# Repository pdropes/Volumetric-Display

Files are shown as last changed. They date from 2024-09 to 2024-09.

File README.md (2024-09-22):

# Volumetric-Display, with ESP32 and LED matrix

VOXEL by #dropes

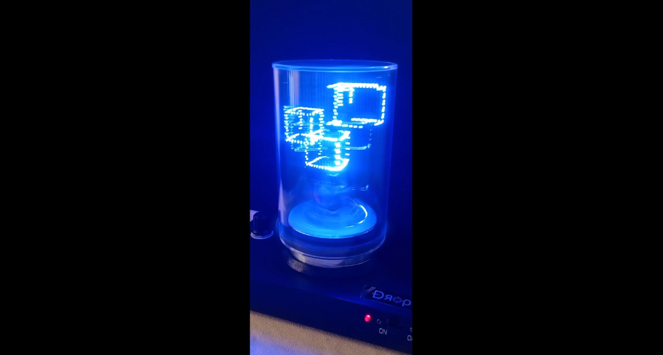
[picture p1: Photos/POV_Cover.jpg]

Video: https://youtu.be/vmjfssugH9E

## VOXEL - HARDWARE

- The motor I used the head of a VCR, after opening it, I placed the power transmitter coils inside, the ferrites had to be filed (very carefully) to fit well and then glued them.
- The distance between the coils is very important and must be calibrated in advance, with the help of a power supply with adjustable maximum current. In the receiver, you must connect a low value resistance 2ohms, or a 20W 12V lamp, with a multimeter to monitor the current passing through it.
- Then the emitter must be supplied with 12V, without progressive increases, the supply must be immediate or it will burn out, maximum current of 2A to start.
- The objective is to have the maximum current measured in the receiver, but without saturating the coils, to do this the distance between the coils is slowly reduced, the current rises to a point, then starts to fall, the distance from the coil must be recorded highest measured current.
- It is likely that the source used in these tests will present a current peak when calibrating the distances. You must be very careful not to overheat both the transmitter and the receiver, and you must immediately move the coils away.
- Both must have a heat sink, both on the two boards and on the emitter power transistors.
- The power supply must be at least 50W, with a voltage of 18V to 24V, with a lower voltage the wireless power transmitter will overheat, requiring more current to compensate.
- The IR transmitter and receiver are inside the head through two holes, this head must rotate without touching anything.
- Assembling all the components requires some skills, if you are not able to solder with an oven or heating plate and hot air station, I recommend ordering the PCBs with the components already soldered, joining the two plates will have to be done later.
- The most difficult are the 1024 “0603 LEDs” and the 64 “controller ICs”.
- The PCBs must have the minimum thickness possible, with 0.6mm being a good value, with the LED controller ICs touching them. Their color doesn't matter much, in rotation it becomes unnoticeable.

More calibrations:
- The 1st balance is static, with the boards horizontal and without the tube, weights must be placed, so that no differences are noticed when rotating manually, always horizontally.
- The dynamic balance was achieved by placing a piezo on one of the legs of the box, visualizing the signal amplitude on the oscilloscope, then placing washers at certain points, where the displayed amplitude reduces.
- The tube alignment must also be done, looking for eccentricity and having as little oscillation as possible.
  
These processes can be tedious and time-consuming, be patient.

## VOXEL - SOFTWARE

Project carried out in Arduino IDE v2.2.1
The 1st programming must be via USB, the rest can be via Wi-Fi for the convenience of keeping the tube, this is the best option, the Arduino-ota routine must be configured in advance, with the name and password of the network to be connected, this part must always remain in the code.
Although you chose the ESP32S2, another type of ESP32 should work, it uses the internal RAM for animations, and the optional PSRAM, for pre-calculation of heavier animations.
The USB connection is direct, without the need for a separate IC for this.
Programming the ESP32 must be done with the engine stopped, in all cases.

Programming steps:
- Connect the VOXEL board directly via USB to the PC.
- Open Arduino, in BOARDS MANAGER, find and install “esp32 by Espressif”
- In LIBRARIES MANAGER, find and install “Arduino_ESP32_OTA by Arduino”
- In TOOLS-BOARDS-ESP32-ESP32S2 Dev Module, choose the COM where the VOXEL is connected
- Check the board settings with the attached file “Arduino V2.2.1 config.png”.
- In VOXEL.INO change the name and password of the local network 
- Compile and upload to ESP32.
- After that, all programming does not require a USB connection, on the Arduino IDE, the Wi-Fi port must be visible.
- If you always intend to program via Wi-Fi, the Arduino-ota settings in VOXEL.ino must remain.

New Animation:
- When programming more effects, you must create a blank file in the same folder, extension .h
- Open VOXEL.ino
- Include the new file name in “FX”
- Next, the “FXlast” declaration, must be changed to the last effect number.
- void ISR_IR, which is the int. that detects the complete turn via IR, the procedure to be carried out in this new effect must be included (check the examples already written).
- void ARDUINO_ISR_ATTR, this is a timer that is run 100 times per turn, the reference of the new effect must also be included, or copy 3 lines from another, so that it can be clearly displayed.
- Shared.h file shares variables between VOXEL.ino and effect.h, or use static variables to avoid conflicts.

## WARNING !
The use of acrylic tube is NECESSARY in this assembly!
It keeps the boards in place at the top, prevents air friction, and ensures GREATER SAFETY to the touch.
Its absence can cause PHYSICAL OR VISION DAMAGE, the rotation speed corresponds to between 25 and 42 km/h!

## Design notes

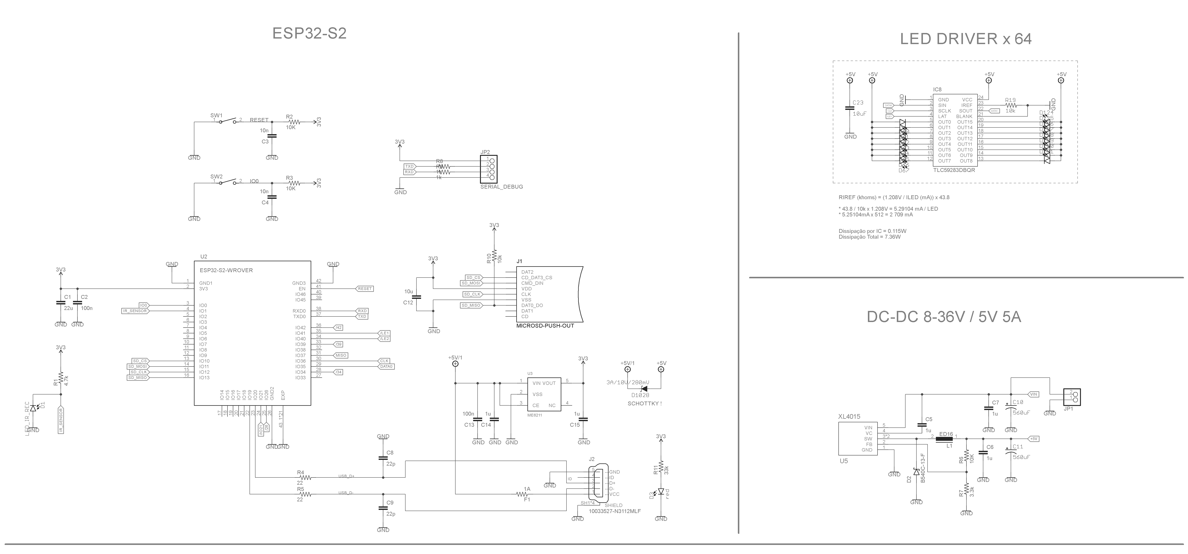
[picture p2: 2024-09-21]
Hardware/Schematic_resume.png

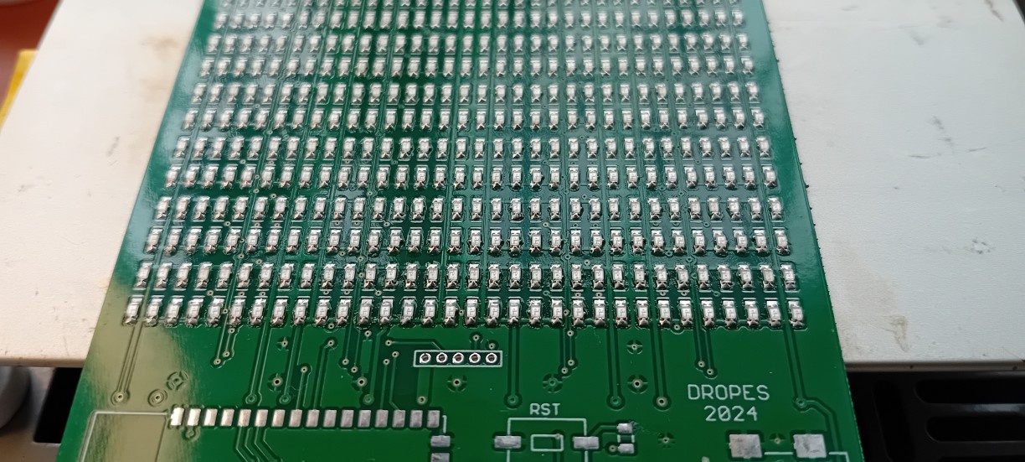
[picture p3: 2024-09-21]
Photos/POV_07.jpg

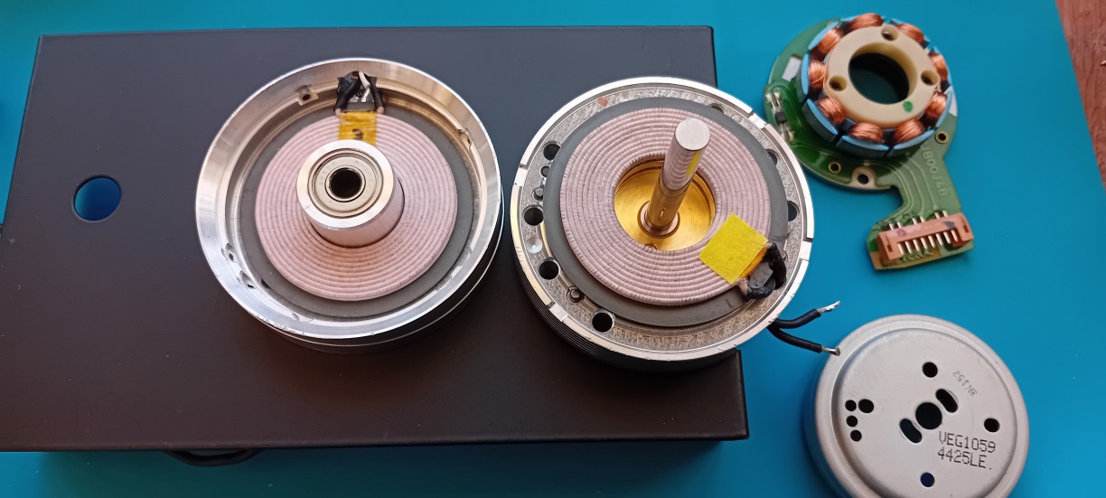
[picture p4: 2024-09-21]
Photos/POV_12.jpg

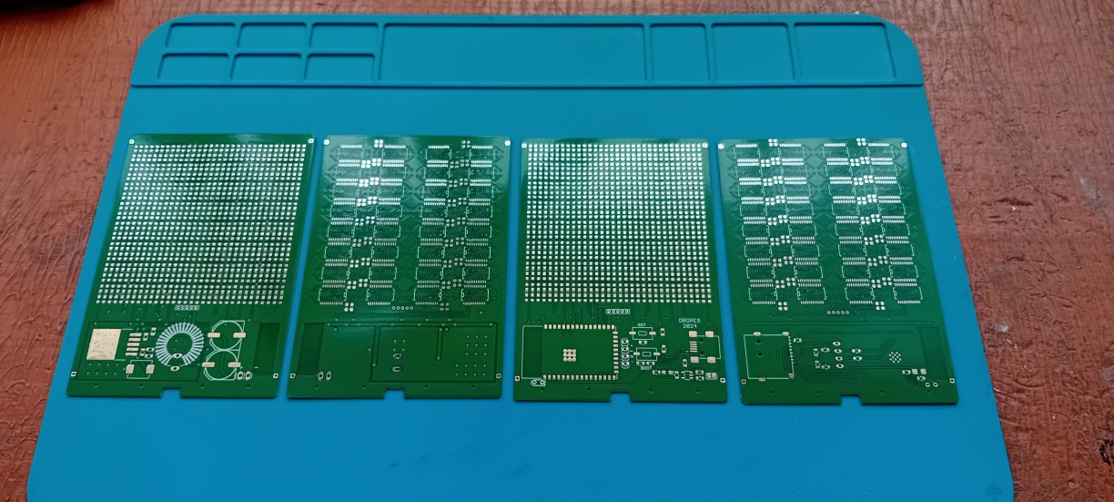
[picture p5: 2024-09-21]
Photos/POV_06.jpg

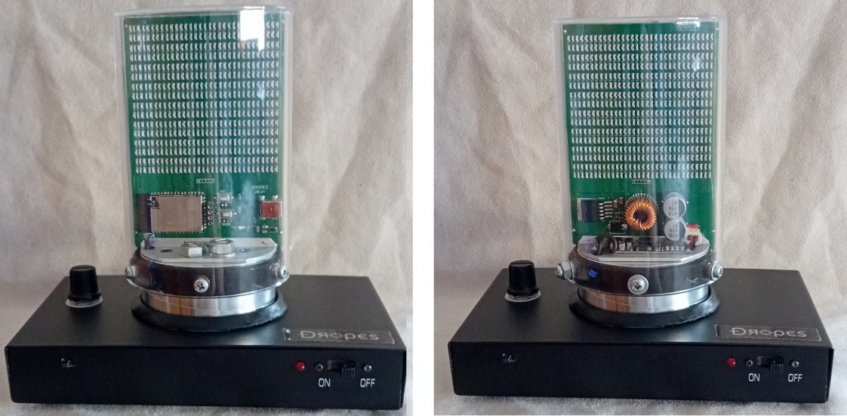
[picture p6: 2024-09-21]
Photos/POV_17.jpg

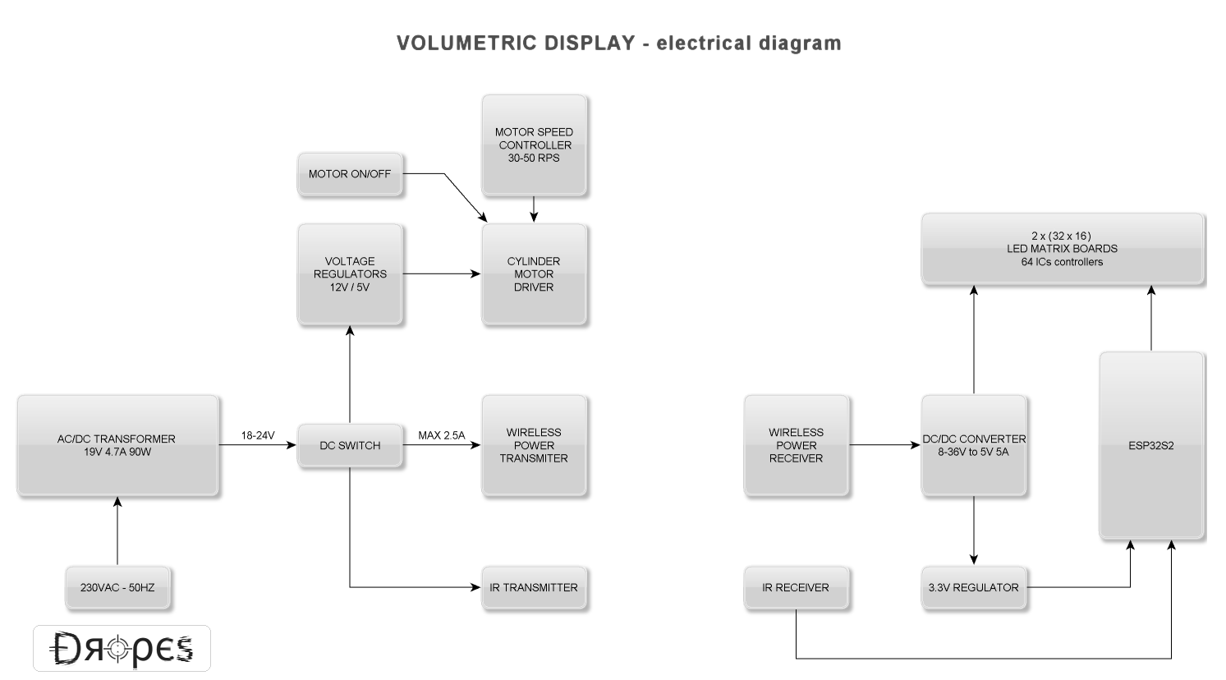
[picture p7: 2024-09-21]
Electrical Diagram.png

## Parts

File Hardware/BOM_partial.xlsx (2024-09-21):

MOUSER | Quantity | Description | Link
TLC59283DBQR | 64 | Drive 16 LEDs | https://pt.mouser.com/ProductDetail/595-TLC59283DBQR
GRM188R60J106KE47J | 64 | 0603 10u 6.3V | https://pt.mouser.com/ProductDetail/81-GRM188R60J106KE7J
CRGH0603J10K | 64 | 0603 10k 0,2W | https://pt.mouser.com/ProductDetail/279-CRGH0603J10K
10033527-N3112MLF | 1 | Mini-USB connector | https://pt.mouser.com/ProductDetail/649-10033527N3112MLF
PTS636 SM25F SMTR LFS | 2 | Micro-switch | https://pt.mouser.com/ProductDetail/611-PTS636SM25FSMTRL
Various passive components |  | Check schematic
ALIEXPRESS | Quantity | Description
Charging board | 2 | xl4015 5A | https://pt.aliexpress.com/item/32711173698.html
LEDs | 2 | 0603 1000 blue LEDs | https://pt.aliexpress.com/item/1005005469107318.html
ME6211 | 1 | LDO 3,3V | https://pt.aliexpress.com/item/1005006036398325.html
Transparent acrylic tube | 1 | Diameter: 75mm / Lenght: 50cm | https://pt.aliexpress.com/item/1005003660995564.html
Wireless power transmitter | 1 | 50W 12-24V 2,5A | https://pt.aliexpress.com/item/1005005666251775.html
DIVERSOS | Quantity | Description
ESP32S2 WROVER | 1 | Flash: 4MB, PSRAM: 2MB | https://mauser.pt/catalog/product_info.php?products_id=096-8584
PCBWAY | 1 | 2 different PCBs per assembly | https://www.pcbway.com/orderonline.aspx
PSRAM is used for some more complex animations, where this is handled in advance at startup
ESP32 with PSRAM, and SD support its optional
Check ESP32 compatibilities when choosing another different module

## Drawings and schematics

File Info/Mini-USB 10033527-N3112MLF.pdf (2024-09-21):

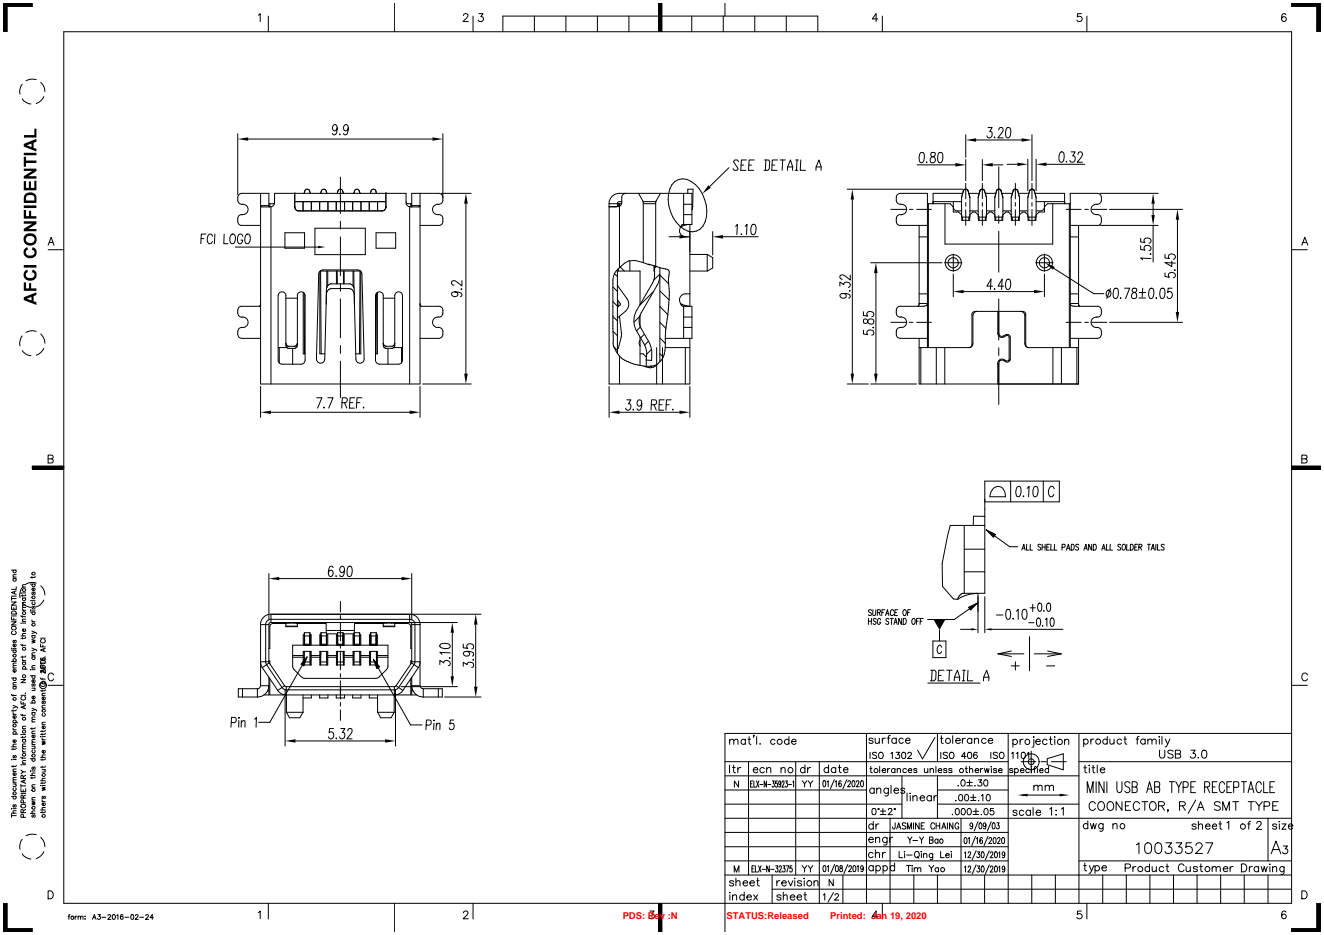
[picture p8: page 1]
PDS: Rev :N; STATUS:Released; Printed: Jan 19, 2020

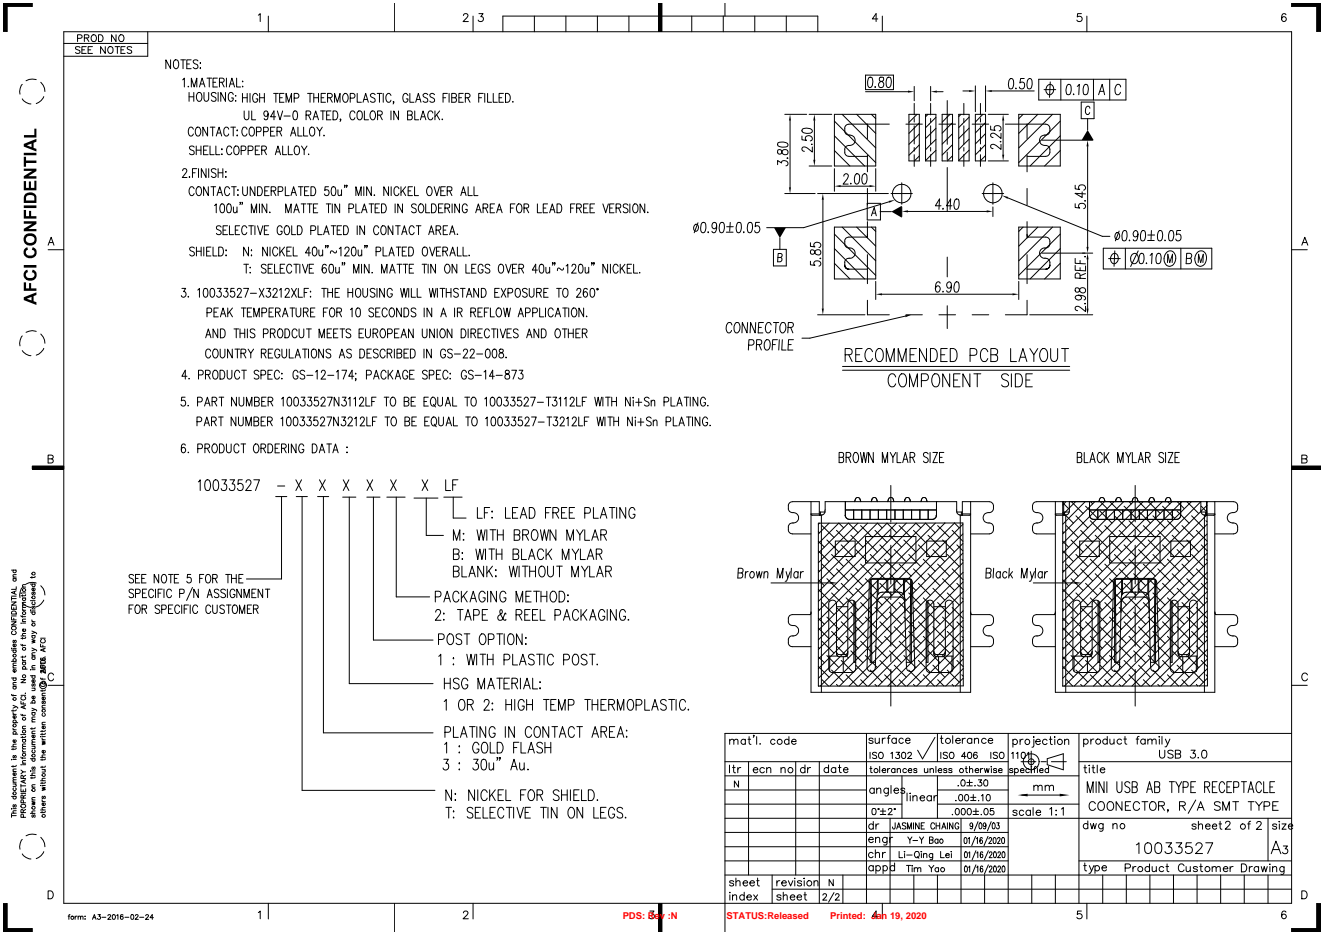
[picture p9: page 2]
PDS: Rev :N; STATUS:Released; Printed: Jan 19, 2020

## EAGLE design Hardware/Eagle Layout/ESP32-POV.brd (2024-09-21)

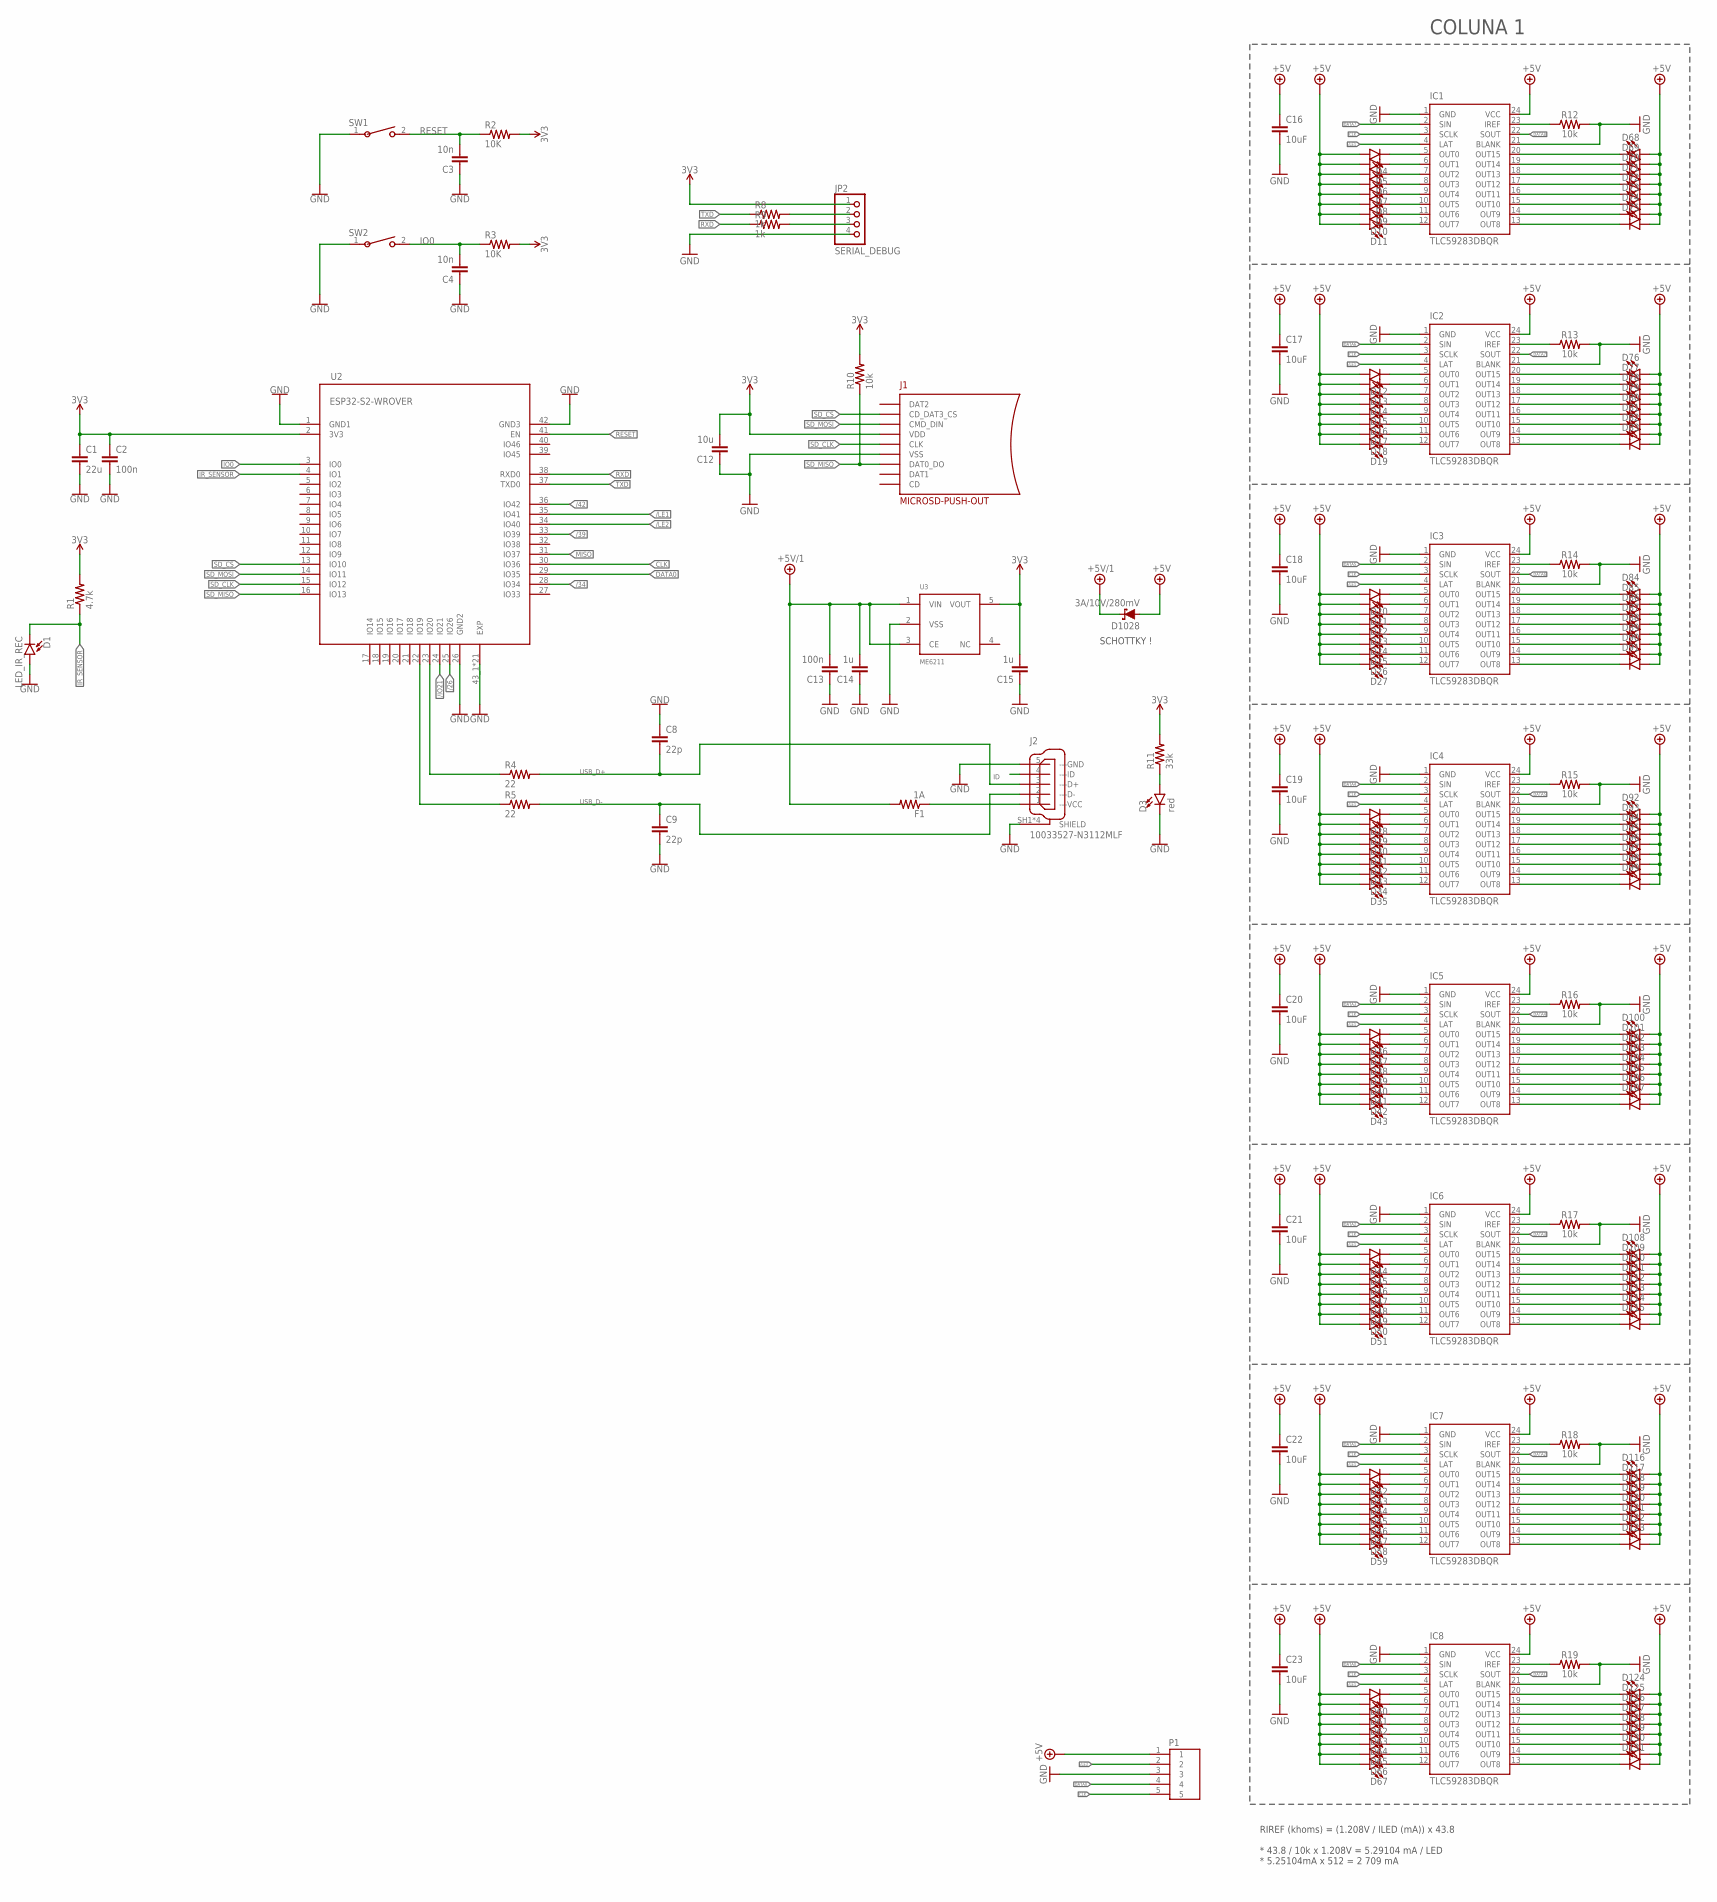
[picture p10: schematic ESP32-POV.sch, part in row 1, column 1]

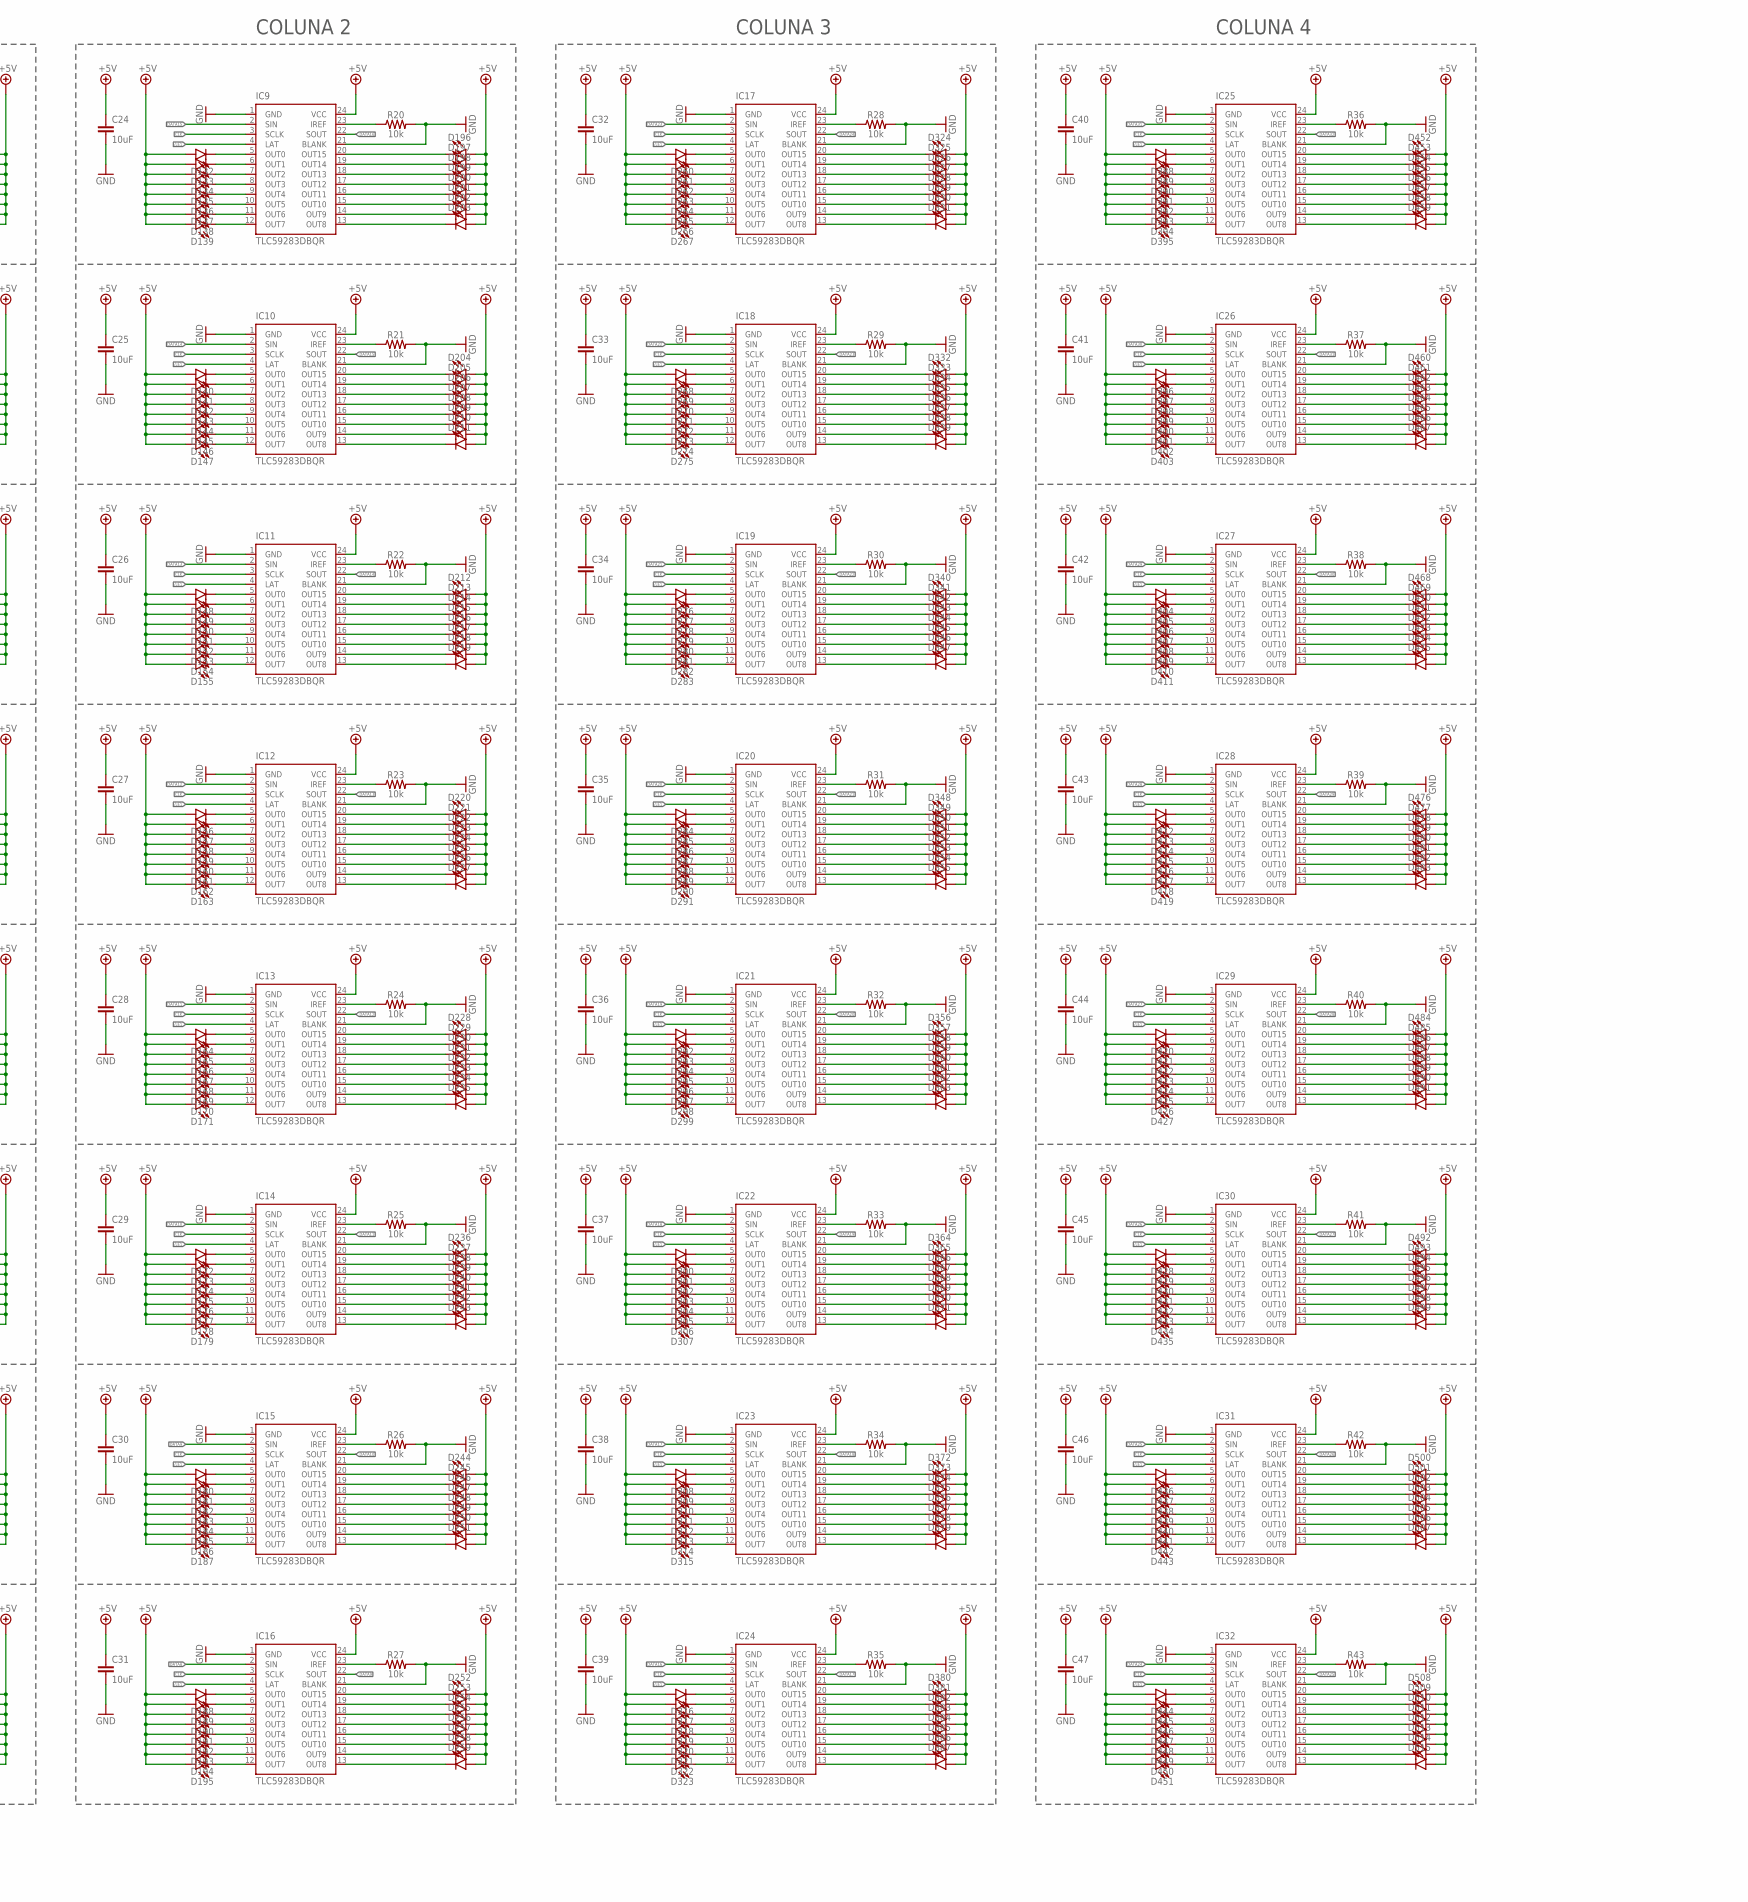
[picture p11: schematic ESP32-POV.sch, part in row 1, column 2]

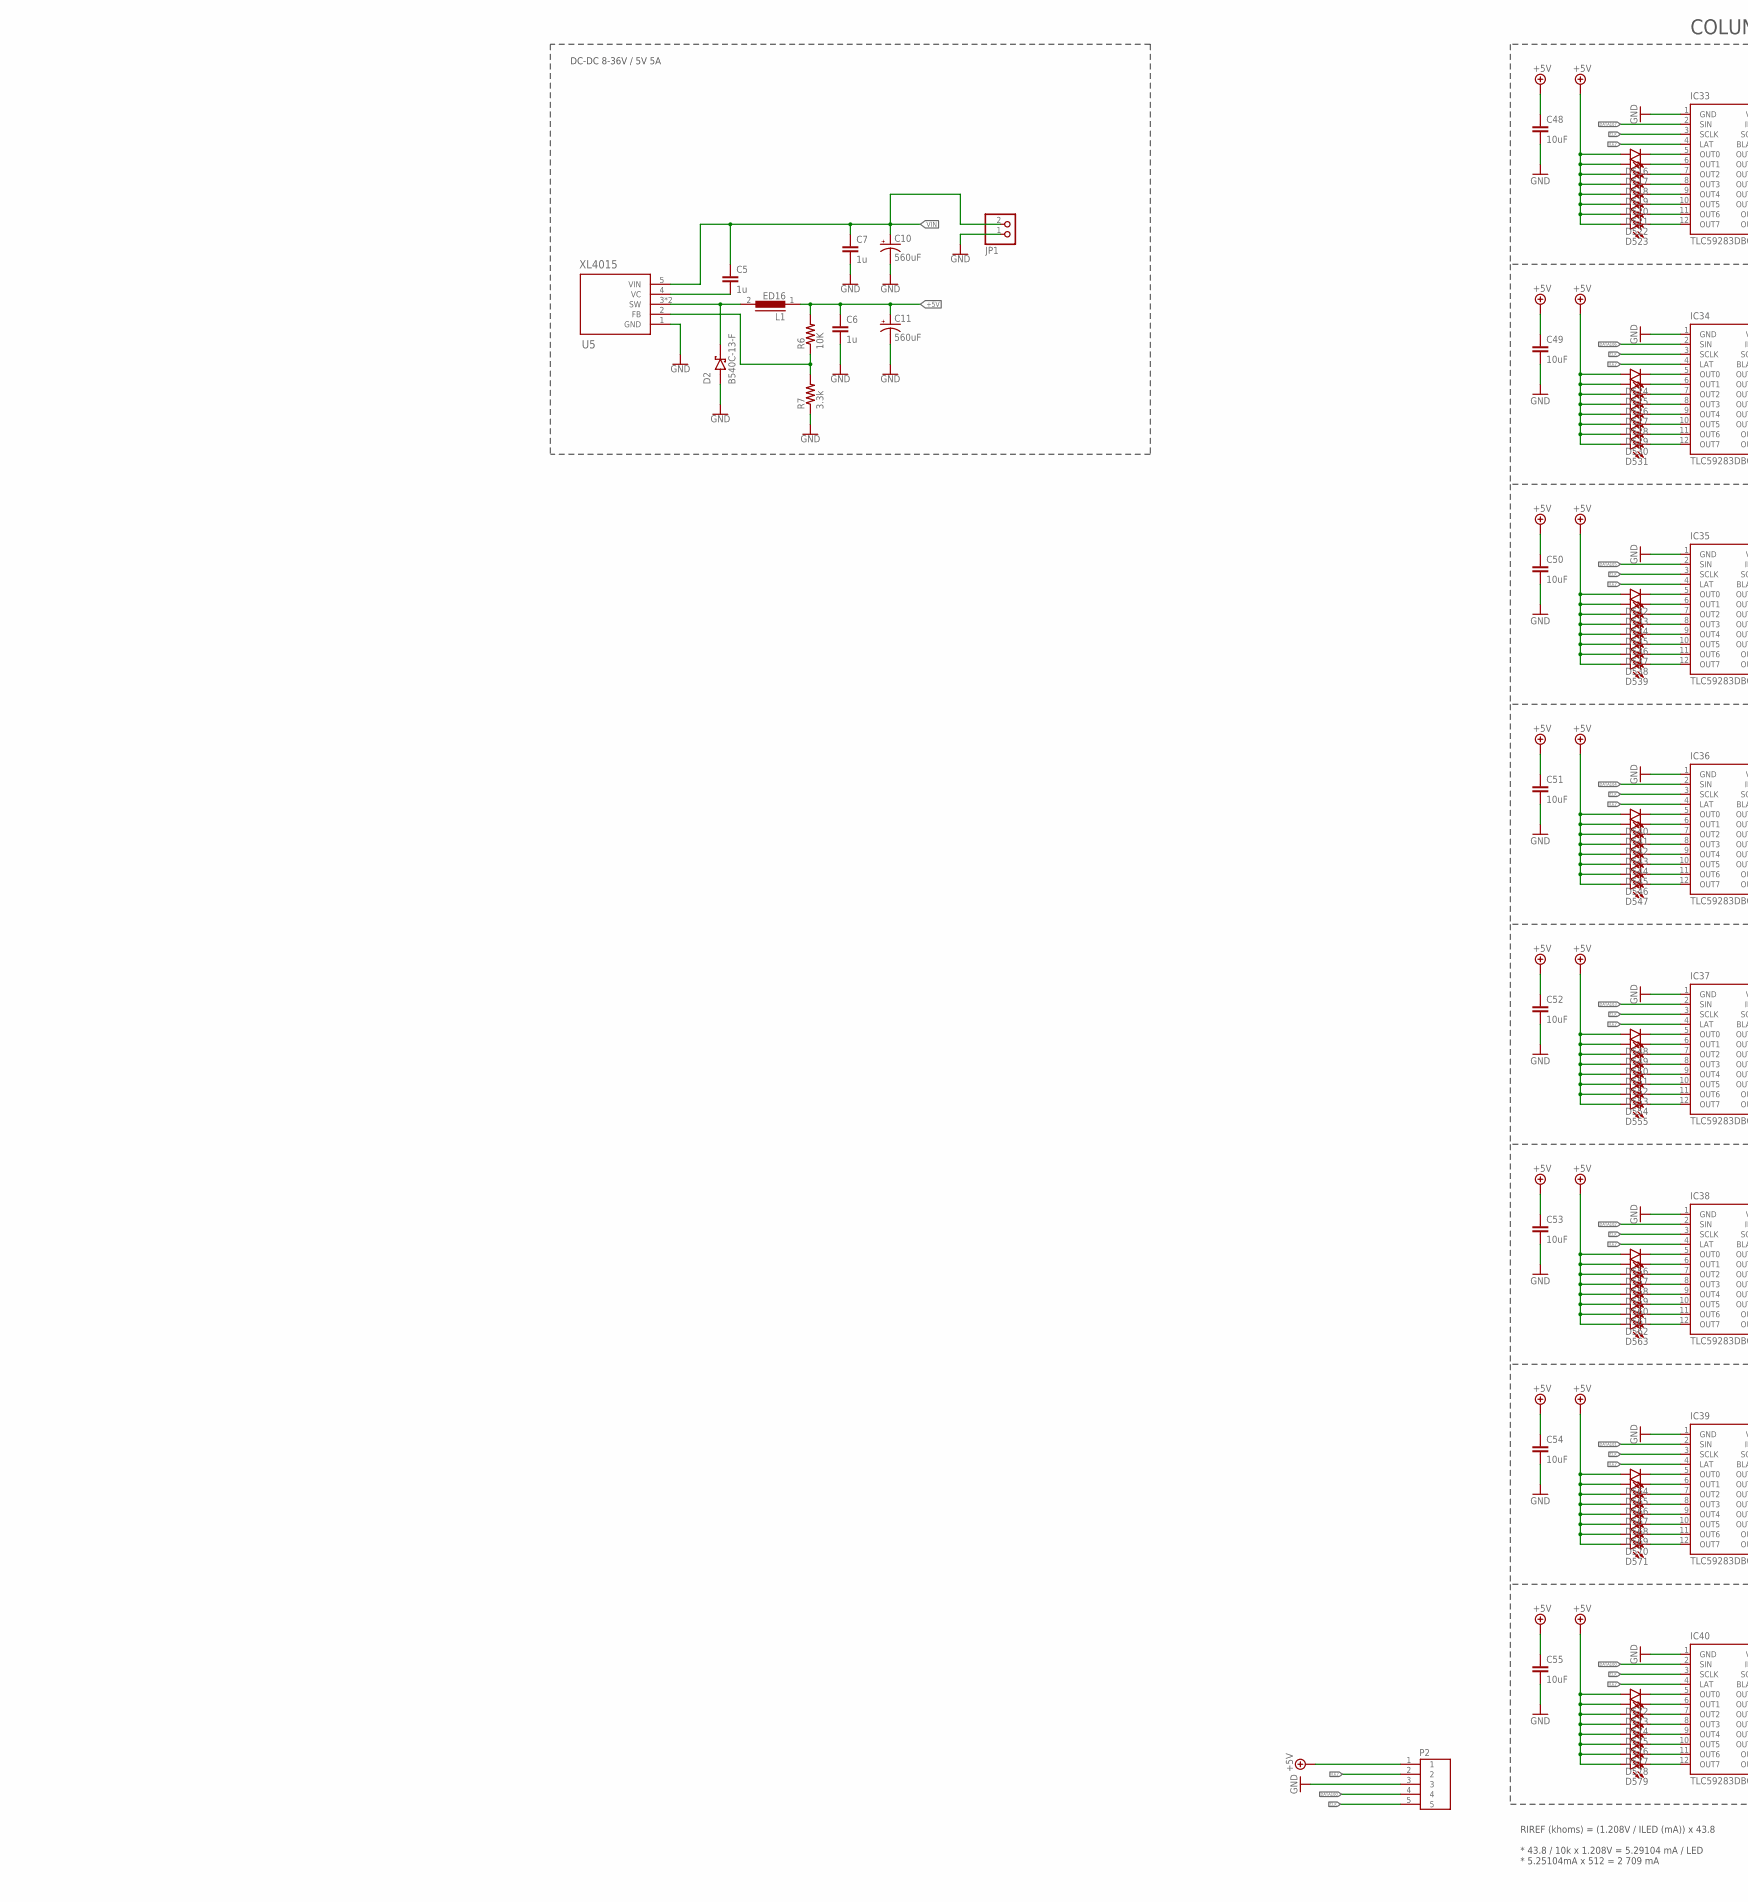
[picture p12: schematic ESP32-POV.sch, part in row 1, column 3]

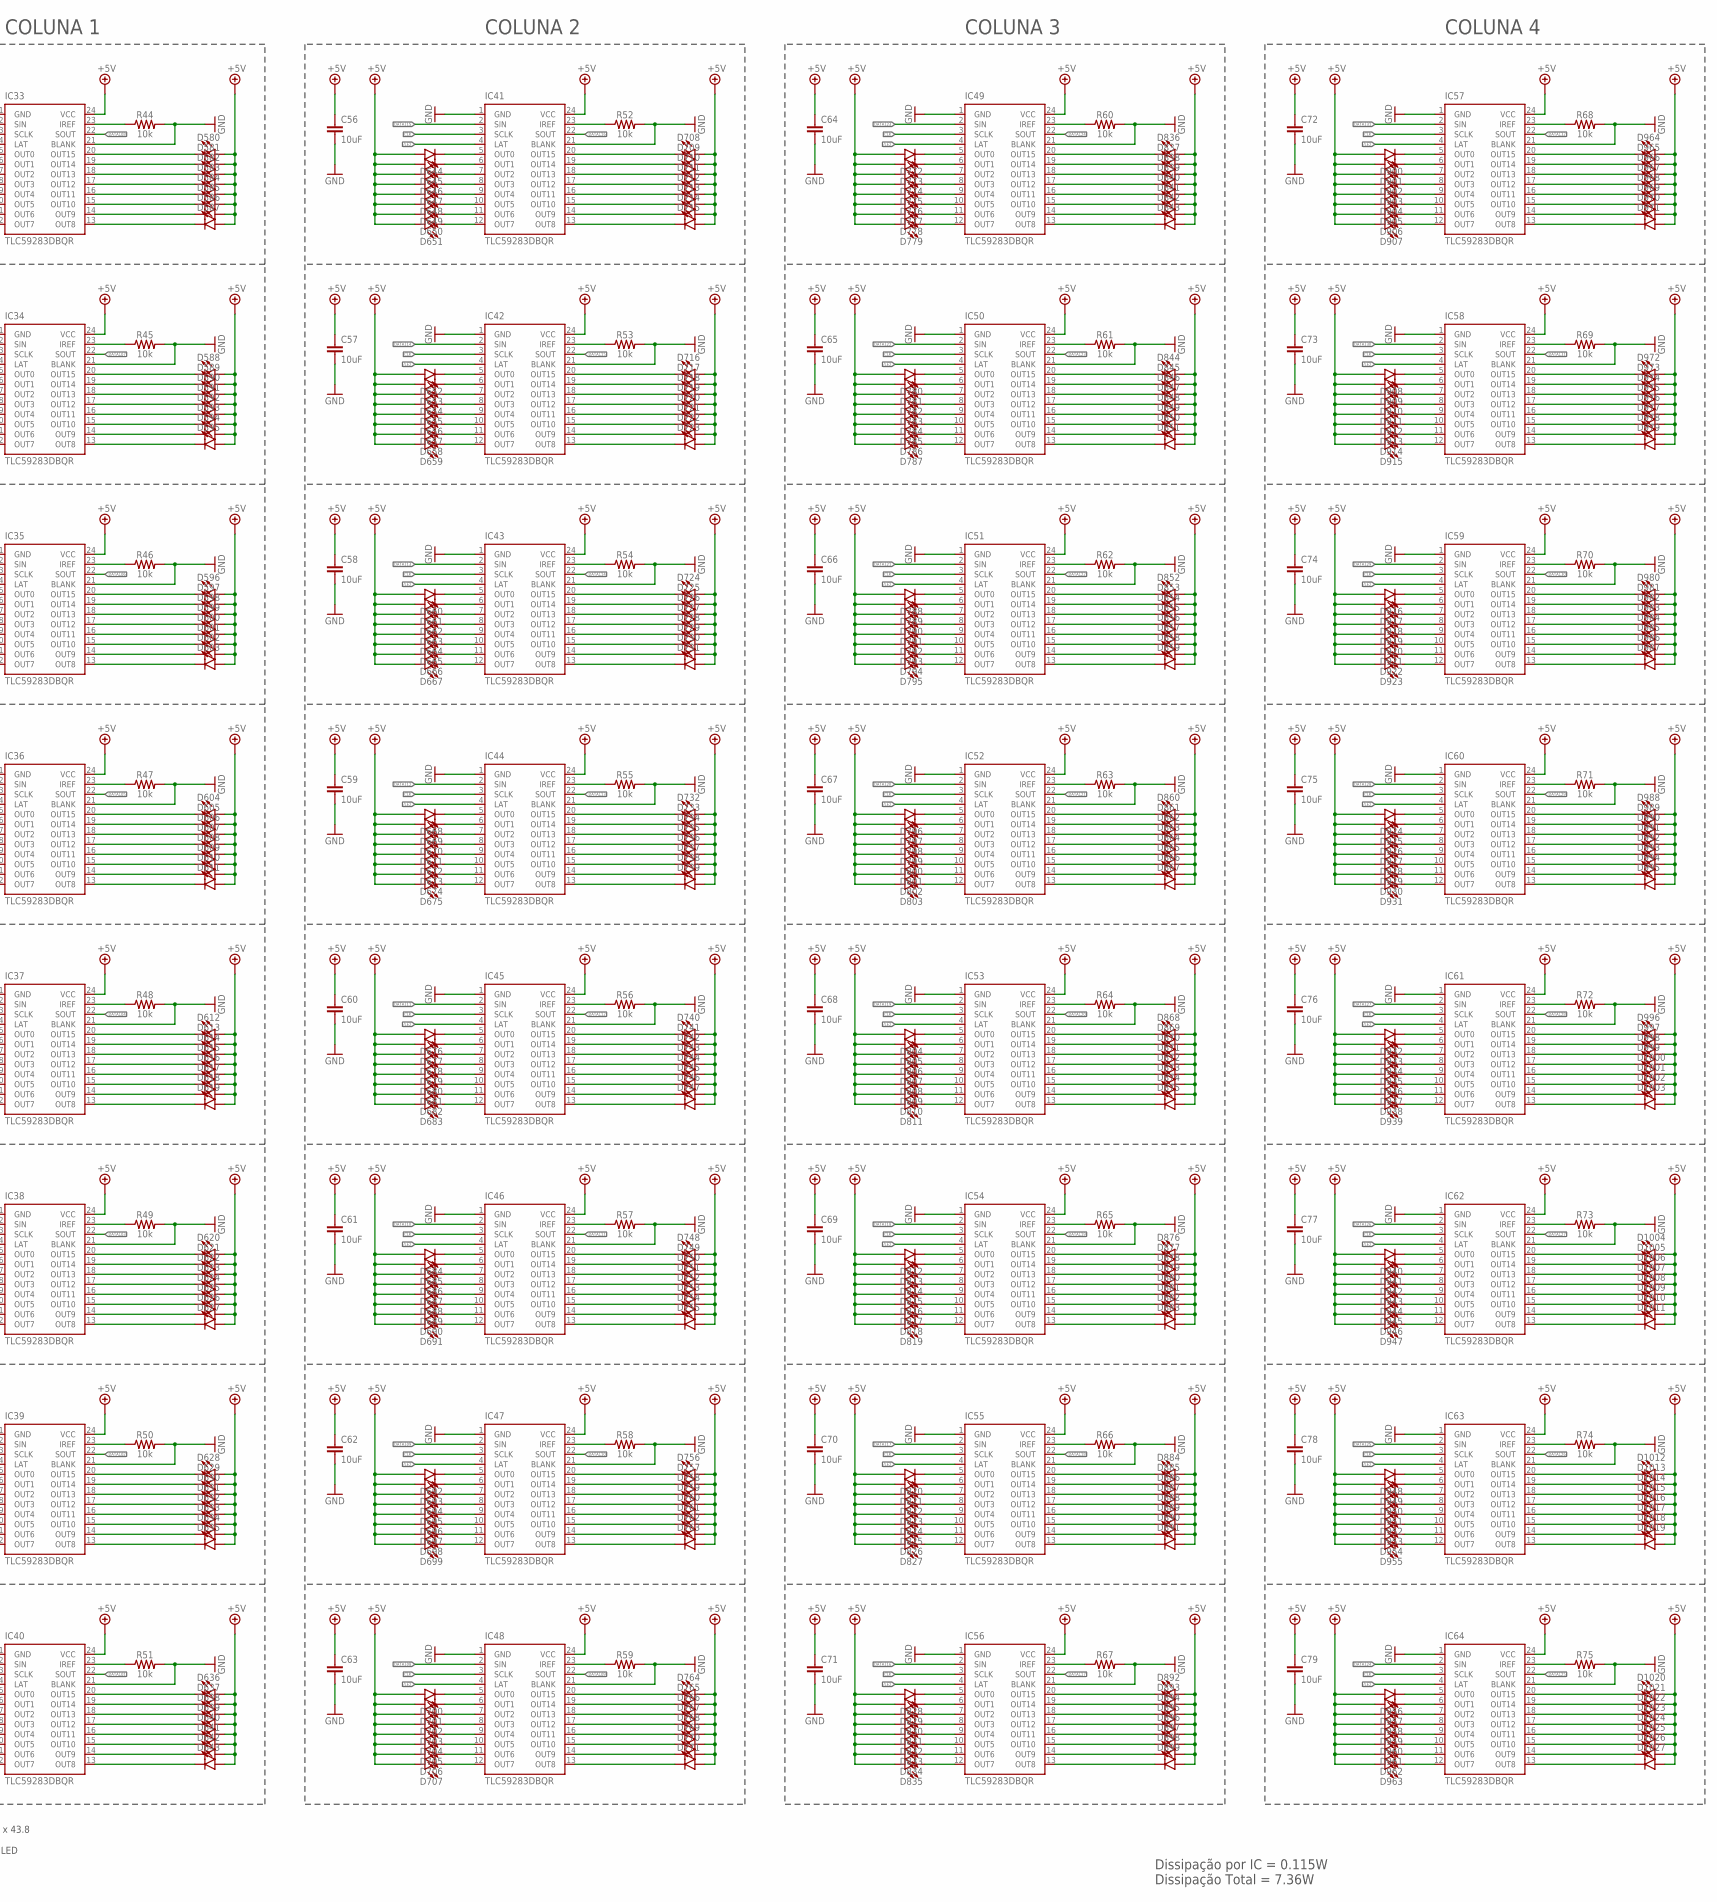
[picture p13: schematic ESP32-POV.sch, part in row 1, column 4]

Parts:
C1: 22u; 1206
C2, C13: 100n; 0805
C3, C4: 10n; 0805
C5, C6, C7, C14, C15: 1u; 0805
C8, C9: 22p; 0805
C10, C11: 560uF; PANASONIC_G
C12: 10u; 0805
C16, C17, C18, C19, C20, C21, C22, C23, C24, C25, C26, C27, C28, C29, C30, C31, C32, C33, C34, C35, C36, C37, C38, C39, C40, C41, C42, C43, C44, C45, C46, C47, C48, C49, C50, C51, C52, C53, C54, C55, C56, C57, C58, C59, C60, C61, C62, C63, C64, C65, C66, C67, C68, C69, C70, C71, C72, C73, C74, C75, C76, C77, C78, C79: 10uF; 0603
D1: LED_IR_REC
D2: B540C-13-F; DIOM6959X245N
D3: red; LED-0805
D4, D5, D6, D7, D8, D9, D10, D11, D12, D13, D14, D15, D16, D17, D18, D19, D20, D21, D22, D23, D24, D25, D26, D27, D28, D29, D30, D31, D32, D33, D34, D35, D36, D37, D38, D39, D40, D41, D42, D43, D44, D45, D46, D47, D48, D49, D50, D51, D52, D53, D54, D55, D56, D57, D58, D59, D60, D61, D62, D63, D64, D65, D66, D67, D68, D69, D70, D71, D72, D73, D74, D75, D76, D77, D78, D79, D80, D81, D82, D83, D84, D85, D86, D87, D88, D89, D90, D91, D92, D93, D94, D95, D96, D97, D98, D99, D100, D101, D102, D103, D104, D105, D106, D107, D108, D109, D110, D111, D112, D113, D114, D115, D116, D117, D118, D119, D120, D121, D122, D123, D124, D125, D126, D127, D128, D129, D130, D131, D132, D133, D134, D135, D136, D137, D138, D139, D140, D141, D142, D143, D144, D145, D146, D147, D148, D149, D150, D151, D152, D153, D154, D155, D156, D157, D158, D159, D160, D161, D162, D163, D164, D165, D166, D167, D168, D169, D170, D171, D172, D173, D174, D175, D176, D177, D178, D179, D180, D181, D182, D183, D184, D185, D186, D187, D188, D189, D190, D191, D192, D193, D194, D195, D196, D197, D198, D199, D200, D201, D202, D203, D204, D205, D206, D207, D208, D209, D210, D211, D212, D213, D214, D215, D216, D217, D218, D219, D220, D221, D222, D223, D224, D225, D226, D227, D228, D229, D230, D231, D232, D233, D234, D235, D236, D237, D238, D239, D240, D241, D242, D243, D244, D245, D246, D247, D248, D249, D250, D251, D252, D253, D254, D255, D256, D257, D258, D259, D260, D261, D262, D263, D264, D265, D266, D267, D268, D269, D270, D271, D272, D273, D274, D275, D276, D277, D278, D279, D280, D281, D282, D283, D284, D285, D286, D287, D288, D289, D290, D291, D292, D293, D294, D295, D296, D297, D298, D299, D300, D301, D302, D303, D304, D305, D306, D307, D308, D309, D310, D311, D312, D313, D314, D315, D316, D317, D318, D319, D320, D321, D322, D323, D324, D325, D326, D327, D328, D329, D330, D331, D332, D333, D334, D335, D336, D337, D338, D339, D340, D341, D342, D343, D344, D345, D346, D347, D348, D349, D350, D351, D352, D353, D354, D355, D356, D357, D358, D359, D360, D361, D362, D363, D364, D365, D366, D367, D368, D369, D370, D371, D372, D373, D374, D375, D376, D377, D378, D379, D380, D381, D382, D383, D384, D385, D386, D387, D388, D389, D390, D391, D392, D393, D394, D395, D396, D397, D398, D399, D400, D401, D402, D403, D404, D405, D406, D407, D408, D409, D410, D411, D412, D413, D414, D415, D416, D417, D418, D419, D420, D421, D422, D423, D424, D425, D426, D427, D428, D429, D430, D431, D432, D433, D434, D435, D436, D437, D438, D439, D440, D441, D442, D443, D444, D445, D446, D447, D448, D449, D450, D451, D452, D453, D454, D455, D456, D457, D458, D459, D460, D461, D462, D463, D464, D465, D466, D467, D468, D469, D470, D471, D472, D473, D474, D475, D476, D477, D478, D479, D480, D481, D482, D483, D484, D485, D486, D487, D488, D489, D490, D491, D492, D493, D494, D495, D496, D497, D498, D499, D500, D501, D502, D503, D504, D505, D506, D507, D508, D509, D510, D511, D512, D513, D514, D515, D516, D517, D518, D519, D520, D521, D522, D523, D524, D525, D526, D527, D528, D529, D530, D531, D532, D533, D534, D535, D536, D537, D538, D539, D540, D541, D542, D543, D544, D545, D546, D547, D548, D549, D550, D551, D552, D553, D554, D555, D556, D557, D558, D559, D560, D561, D562, D563, D564, D565, D566, D567, D568, D569, D570, D571, D572, D573, D574, D575, D576, D577, D578, D579, D580, D581, D582, D583, D584, D585, D586, D587, D588, D589, D590, D591, D592, D593, D594, D595, D596, D597, D598, D599, D600, D601, D602, D603, D604, D605, D606, D607, D608, D609, D610, D611, D612, D613, D614, D615, D616, D617, D618, D619, D620, D621, D622, D623, D624, D625, D626, D627, D628, D629, D630, D631, D632, D633, D634, D635, D636, D637, D638, D639, D640, D641, D642, D643, D644, D645, D646, D647, D648, D649, D650, D651, D652, D653, D654, D655, D656, D657, D658, D659, D660, D661, D662, D663, D664, D665, D666, D667, D668, D669, D670, D671, D672, D673, D674, D675, D676, D677, D678, D679, D680, D681, D682, D683, D684, D685, D686, D687, D688, D689, D690, D691, D692, D693, D694, D695, D696, D697, D698, D699, D700, D701, D702, D703, D704, D705, D706, D707, D708, D709, D710, D711, D712, D713, D714, D715, D716, D717, D718, D719, D720, D721, D722, D723, D724, D725, D726, D727, D728, D729, D730, D731, D732, D733, D734, D735, D736, D737, D738, D739, D740, D741, D742, D743, D744, D745, D746, D747, D748, D749, D750, D751, D752, D753, D754, D755, D756, D757, D758, D759, D760, D761, D762, D763, D764, D765, D766, D767, D768, D769, D770, D771, D772, D773, D774, D775, D776, D777, D778, D779, D780, D781, D782, D783, D784, D785, D786, D787, D788, D789, D790, D791, D792, D793, D794, D795, D796, D797, D798, D799, D800, D801, D802, D803, D804, D805, D806, D807, D808, D809, D810, D811, D812, D813, D814, D815, D816, D817, D818, D819, D820, D821, D822, D823, D824, D825, D826, D827, D828, D829, D830, D831, D832, D833, D834, D835, D836, D837, D838, D839, D840, D841, D842, D843, D844, D845, D846, D847, D848, D849, D850, D851, D852, D853, D854, D855, D856, D857, D858, D859, D860, D861, D862, D863, D864, D865, D866, D867, D868, D869, D870, D871, D872, D873, D874, D875, D876, D877, D878, D879, D880, D881, D882, D883, D884, D885, D886, D887, D888, D889, D890, D891, D892, D893, D894, D895, D896, D897, D898, D899, D900, D901, D902, D903, D904, D905, D906, D907, D908, D909, D910, D911, D912, D913, D914, D915, D916, D917, D918, D919, D920, D921, D922, D923, D924, D925, D926, D927, D928, D929, D930, D931, D932, D933, D934, D935, D936, D937, D938, D939, D940, D941, D942, D943, D944, D945, D946, D947, D948, D949, D950, D951, D952, D953, D954, D955, D956, D957, D958, D959, D960, D961, D962, D963, D964, D965, D966, D967, D968, D969, D970, D971, D972, D973, D974, D975, D976, D977, D978, D979, D980, D981, D982, D983, D984, D985, D986, D987, D988, D989, D990, D991, D992, D993, D994, D995, D996, D997, D998, D999, D1000, D1001, D1002, D1003, D1004, D1005, D1006, D1007, D1008, D1009, D1010, D1011, D1012, D1013, D1014, D1015, D1016, D1017, D1018, D1019, D1020, D1021, D1022, D1023, D1024, D1025, D1026, D1027: LED-BLUE0603; LED-0603
D1028: 3A/10V/280mV; SOD-323
F1: 1A; 0805
IC1, IC2, IC3, IC4, IC5, IC6, IC7, IC8, IC9, IC10, IC11, IC12, IC13, IC14, IC15, IC16, IC17, IC18, IC19, IC20, IC21, IC22, IC23, IC24, IC25, IC26, IC27, IC28, IC29, IC30, IC31, IC32, IC33, IC34, IC35, IC36, IC37, IC38, IC39, IC40, IC41, IC42, IC43, IC44, IC45, IC46, IC47, IC48, IC49, IC50, IC51, IC52, IC53, IC54, IC55, IC56, IC57, IC58, IC59, IC60, IC61, IC62, IC63, IC64: TLC59283DBQR; DBQ24_TEX
J1: MICROSD-PUSH-OUT
J2: 10033527-N3112MLF; AMPHENOL_10033527-N3112MLF
JP1: PINHD-1X2; 1X02
JP2: SERIAL_DEBUG; PINHEAD_1X04
L1: ED16
P1, P2: HEADER5
R1: 4.7k; 0805
R2, R3, R6: 10K; 0805
R4, R5: 22; 0805
R7: 3.3k; 0805
R8, R9: 1k; 0805
R10: 10k; 0805
R11: 33k; 0805
R12, R13, R14, R15, R16, R17, R18, R19, R20, R21, R22, R23, R24, R25, R26, R27, R28, R29, R30, R31, R32, R33, R34, R35, R36, R37, R38, R39, R40, R41, R42, R43, R44, R45, R46, R47, R48, R49, R50, R51, R52, R53, R54, R55, R56, R57, R58, R59, R60, R61, R62, R63, R64, R65, R66, R67, R68, R69, R70, R71, R72, R73, R74, R75: 10k; 0603
SW1, SW2: PTS636_SM25F_SMTR_LFS; SW2_PTS636_SM25F_SMTR_LFS_CNK
U2: ESP32-S2-WROVER; MODULE_ESP32-S2-WROVER
U3: ME6211; SOT23-5
U5: XL4015; TO263-5L_DIO

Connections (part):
+5V: C6.1, C11.+, C16.1, C17.1, C18.1, C19.1, C20.1, C21.1, C22.1, C23.1, C24.1, C25.1, C26.1, C27.1, C28.1, C29.1, C30.1, C31.1, C32.1, C33.1, C34.1, C35.1, C36.1, C37.1, C38.1, C39.1, C40.1, C41.1, C42.1, C43.1, C44.1, C45.1, C46.1, C47.1, C48.1, C49.1, C50.1, C51.1, C52.1, C53.1, C54.1, C55.1, C56.1, C57.1, C58.1, C59.1, C60.1, C61.1, C62.1, C63.1, C64.1, C65.1, C66.1, C67.1, C68.1, C69.1, C70.1, C71.1, C72.1, C73.1, C74.1, C75.1, C76.1, C77.1, C78.1, C79.1, D4.A, D5.A, D6.A, D7.A, D8.A, D9.A, D10.A, D11.A, D12.A, D13.A, D14.A, D15.A, D16.A, D17.A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
+5V/1: C13.2, C14.2, D1028.C, F1.2, U3.1 (VIN), U3.3 (CE)
/26: U2.25 (IO26)
/34: U2.28 (IO34)
/39: U2.33 (IO39)
/42: U2.36 (IO42)
/IO21: U2.24 (IO21)
/LE1: IC1.4 (LAT), IC2.4 (LAT), IC3.4 (LAT), IC4.4 (LAT), IC5.4 (LAT), IC6.4 (LAT), IC7.4 (LAT), IC8.4 (LAT), IC9.4 (LAT), IC10.4 (LAT), IC11.4 (LAT), IC12.4 (LAT), IC13.4 (LAT), IC14.4 (LAT), IC15.4 (LAT), IC16.4 (LAT), IC17.4 (LAT), IC18.4 (LAT), IC19.4 (LAT), IC20.4 (LAT), IC21.4 (LAT), IC22.4 (LAT), IC23.4 (LAT), IC24.4 (LAT), IC25.4 (LAT), IC26.4 (LAT), IC27.4 (LAT), IC28.4 (LAT), IC29.4 (LAT), IC30.4 (LAT), IC31.4 (LAT), IC32.4 (LAT), U2.35 (IO41)
/LE2: IC33.4 (LAT), IC34.4 (LAT), IC35.4 (LAT), IC36.4 (LAT), IC37.4 (LAT), IC38.4 (LAT), IC39.4 (LAT), IC40.4 (LAT), IC41.4 (LAT), IC42.4 (LAT), IC43.4 (LAT), IC44.4 (LAT), IC45.4 (LAT), IC46.4 (LAT), IC47.4 (LAT), IC48.4 (LAT), IC49.4 (LAT), IC50.4 (LAT), IC51.4 (LAT), IC52.4 (LAT), IC53.4 (LAT), IC54.4 (LAT), IC55.4 (LAT), IC56.4 (LAT), IC57.4 (LAT), IC58.4 (LAT), IC59.4 (LAT), IC60.4 (LAT), IC61.4 (LAT), IC62.4 (LAT), IC63.4 (LAT), IC64.4 (LAT), P1.2, P2.2, U2.34 (IO40)
CLK: IC1.3 (SCLK), IC2.3 (SCLK), IC3.3 (SCLK), IC4.3 (SCLK), IC5.3 (SCLK), IC6.3 (SCLK), IC7.3 (SCLK), IC8.3 (SCLK), IC9.3 (SCLK), IC10.3 (SCLK), IC11.3 (SCLK), IC12.3 (SCLK), IC13.3 (SCLK), IC14.3 (SCLK), IC15.3 (SCLK), IC16.3 (SCLK), IC17.3 (SCLK), IC18.3 (SCLK), IC19.3 (SCLK), IC20.3 (SCLK), IC21.3 (SCLK), IC22.3 (SCLK), IC23.3 (SCLK), IC24.3 (SCLK), IC25.3 (SCLK), IC26.3 (SCLK), IC27.3 (SCLK), IC28.3 (SCLK), IC29.3 (SCLK), IC30.3 (SCLK), IC31.3 (SCLK), IC32.3 (SCLK), IC33.3 (SCLK), IC34.3 (SCLK), IC35.3 (SCLK), IC36.3 (SCLK), IC37.3 (SCLK), IC38.3 (SCLK), IC39.3 (SCLK), IC40.3 (SCLK), IC41.3 (SCLK), IC42.3 (SCLK), IC43.3 (SCLK), IC44.3 (SCLK), IC45.3 (SCLK), IC46.3 (SCLK), IC47.3 (SCLK), IC48.3 (SCLK), IC49.3 (SCLK), IC50.3 (SCLK), IC51.3 (SCLK), IC52.3 (SCLK), IC53.3 (SCLK), IC54.3 (SCLK), IC55.3 (SCLK), IC56.3 (SCLK), IC57.3 (SCLK), IC58.3 (SCLK), IC59.3 (SCLK), IC60.3 (SCLK), IC61.3 (SCLK), IC62.3 (SCLK), IC63.3 (SCLK), IC64.3 (SCLK), P1.5, P2.5, U2.30 (IO36)
DATA0: IC8.2 (SIN), P1.4, U2.29 (IO35)
DATA1: IC7.2 (SIN), IC8.22 (SOUT)
DATA2: IC6.2 (SIN), IC7.22 (SOUT)
DATA3: IC5.2 (SIN), IC6.22 (SOUT)
DATA4: IC4.2 (SIN), IC5.22 (SOUT)
DATA5: IC3.2 (SIN), IC4.22 (SOUT)
DATA6: IC2.2 (SIN), IC3.22 (SOUT)
DATA7: IC1.2 (SIN), IC2.22 (SOUT)
DATA8: IC1.22 (SOUT), IC16.2 (SIN)
DATA9: IC15.2 (SIN), IC16.22 (SOUT)
DATA10: IC14.2 (SIN), IC15.22 (SOUT)
DATA11: IC13.2 (SIN), IC14.22 (SOUT)
DATA12: IC12.2 (SIN), IC13.22 (SOUT)
DATA13: IC11.2 (SIN), IC12.22 (SOUT)
DATA14: IC10.2 (SIN), IC11.22 (SOUT)
DATA15: IC9.2 (SIN), IC10.22 (SOUT)
DATA16: IC9.22 (SOUT), IC24.2 (SIN)
DATA17: IC23.2 (SIN), IC24.22 (SOUT)
DATA18: IC22.2 (SIN), IC23.22 (SOUT)
DATA19: IC21.2 (SIN), IC22.22 (SOUT)
DATA20: IC20.2 (SIN), IC21.22 (SOUT)
DATA21: IC19.2 (SIN), IC20.22 (SOUT)
DATA22: IC18.2 (SIN), IC19.22 (SOUT)
DATA23: IC17.2 (SIN), IC18.22 (SOUT)
DATA24: IC17.22 (SOUT), IC32.2 (SIN)
DATA25: IC31.2 (SIN), IC32.22 (SOUT)
DATA26: IC30.2 (SIN), IC31.22 (SOUT)
DATA27: IC29.2 (SIN), IC30.22 (SOUT)
DATA28: IC28.2 (SIN), IC29.22 (SOUT)
DATA29: IC27.2 (SIN), IC28.22 (SOUT)
DATA30: IC26.2 (SIN), IC27.22 (SOUT)
DATA31: IC25.2 (SIN), IC26.22 (SOUT)
DATA32: IC25.22 (SOUT)
DATA100: IC40.2 (SIN), P2.4
DATA101: IC39.2 (SIN), IC40.22 (SOUT)
DATA102: IC38.2 (SIN), IC39.22 (SOUT)
DATA103: IC37.2 (SIN), IC38.22 (SOUT)
DATA104: IC36.2 (SIN), IC37.22 (SOUT)
DATA105: IC35.2 (SIN), IC36.22 (SOUT)
DATA106: IC34.2 (SIN), IC35.22 (SOUT)
DATA107: IC33.2 (SIN), IC34.22 (SOUT)
DATA108: IC33.22 (SOUT), IC48.2 (SIN)
DATA109: IC47.2 (SIN), IC48.22 (SOUT)
DATA110: IC46.2 (SIN), IC47.22 (SOUT)
DATA111: IC45.2 (SIN), IC46.22 (SOUT)
DATA112: IC44.2 (SIN), IC45.22 (SOUT)
DATA113: IC43.2 (SIN), IC44.22 (SOUT)
DATA114: IC42.2 (SIN), IC43.22 (SOUT)
DATA115: IC41.2 (SIN), IC42.22 (SOUT)
DATA116: IC41.22 (SOUT), IC56.2 (SIN)
DATA117: IC55.2 (SIN), IC56.22 (SOUT)
DATA118: IC54.2 (SIN), IC55.22 (SOUT)
DATA119: IC53.2 (SIN), IC54.22 (SOUT)
DATA120: IC52.2 (SIN), IC53.22 (SOUT)
DATA121: IC51.2 (SIN), IC52.22 (SOUT)
DATA122: IC50.2 (SIN), IC51.22 (SOUT)
DATA123: IC49.2 (SIN), IC50.22 (SOUT)
DATA124: IC49.22 (SOUT), IC64.2 (SIN)
DATA125: IC63.2 (SIN), IC64.22 (SOUT)
DATA126: IC62.2 (SIN), IC63.22 (SOUT)
DATA127: IC61.2 (SIN), IC62.22 (SOUT)
DATA128: IC60.2 (SIN), IC61.22 (SOUT)
DATA129: IC59.2 (SIN), IC60.22 (SOUT)
DATA130: IC58.2 (SIN), IC59.22 (SOUT)
DATA131: IC57.2 (SIN), IC58.22 (SOUT)
DATA132: IC57.22 (SOUT)
GND: C1.2, C2.2, C3.1, C4.1, C6.2, C7.2, C8.1, C9.2, C10.-, C11.-, C12.1, C13.1, C14.1, C15.1, C16.2, C17.2, C18.2, C19.2, C20.2, C21.2, C22.2, C23.2, C24.2, C25.2, C26.2, C27.2, C28.2, C29.2, C30.2, C31.2, C32.2, C33.2, C34.2, C35.2, C36.2, C37.2, C38.2, C39.2, C40.2, C41.2, C42.2, C43.2, C44.2, C45.2, C46.2, C47.2, C48.2, C49.2, C50.2, C51.2, C52.2, C53.2, C54.2, C55.2, C56.2, C57.2, C58.2, C59.2, C60.2, C61.2, C62.2, C63.2, C64.2, C65.2, C66.2, C67.2, C68.2, C69.2, C70.2, C71.2, C72.2, C73.2, C74.2, C75.2, C76.2, C77.2, C78.2, C79.2, D1.A, D2.A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
ID: J2.4 (---ID)
IO0: C4.2, R3.1, SW2.2, U2.3 (IO0)
IO52: R4.1, U2.23 (IO20)
IO53: R5.1, U2.22 (IO19)
IR_SENSOR: D1.K (C), R1.1, U2.4 (IO1)
MISO: U2.31 (IO37)
unnamed: D52.C, IC7.5 (OUT0)
unnamed: D53.C, IC7.6 (OUT1)
unnamed: D54.C, IC7.7 (OUT2)
unnamed: D55.C, IC7.8 (OUT3)
unnamed: D56.C, IC7.9 (OUT4)
unnamed: D58.C, IC7.11 (OUT6)
unnamed: D59.C, IC7.12 (OUT7)
unnamed: D123.C, IC7.13 (OUT8)
unnamed: D122.C, IC7.14 (OUT9)
unnamed: D121.C, IC7.15 (OUT10)
unnamed: D120.C, IC7.16 (OUT11)
unnamed: D119.C, IC7.17 (OUT12)
unnamed: D118.C, IC7.18 (OUT13)
unnamed: D117.C, IC7.19 (OUT14)
unnamed: D116.C, IC7.20 (OUT15)
unnamed: D57.C, IC7.10 (OUT5)
unnamed: IC7.23 (IREF), R18.1
unnamed: D44.C, IC6.5 (OUT0)
unnamed: D45.C, IC6.6 (OUT1)
unnamed: D46.C, IC6.7 (OUT2)
unnamed: D47.C, IC6.8 (OUT3)
unnamed: D48.C, IC6.9 (OUT4)
unnamed: D50.C, IC6.11 (OUT6)
unnamed: D51.C, IC6.12 (OUT7)
unnamed: D115.C, IC6.13 (OUT8)
unnamed: D114.C, IC6.14 (OUT9)
unnamed: D113.C, IC6.15 (OUT10)
unnamed: D112.C, IC6.16 (OUT11)
unnamed: D111.C, IC6.17 (OUT12)
unnamed: D110.C, IC6.18 (OUT13)
unnamed: D109.C, IC6.19 (OUT14)
unnamed: D108.C, IC6.20 (OUT15)
unnamed: D49.C, IC6.10 (OUT5)
unnamed: IC6.23 (IREF), R17.1
unnamed: D572.C, IC40.5 (OUT0)
unnamed: D36.C, IC5.5 (OUT0)
unnamed: D37.C, IC5.6 (OUT1)
unnamed: D38.C, IC5.7 (OUT2)
unnamed: D39.C, IC5.8 (OUT3)
unnamed: D40.C, IC5.9 (OUT4)
unnamed: D42.C, IC5.11 (OUT6)
unnamed: D43.C, IC5.12 (OUT7)
unnamed: D107.C, IC5.13 (OUT8)
unnamed: D106.C, IC5.14 (OUT9)
unnamed: D105.C, IC5.15 (OUT10)
unnamed: D104.C, IC5.16 (OUT11)
unnamed: D103.C, IC5.17 (OUT12)
unnamed: D102.C, IC5.18 (OUT13)
unnamed: D101.C, IC5.19 (OUT14)
unnamed: D100.C, IC5.20 (OUT15)
unnamed: D41.C, IC5.10 (OUT5)
unnamed: IC5.23 (IREF), R16.1
unnamed: D28.C, IC4.5 (OUT0)
unnamed: D29.C, IC4.6 (OUT1)
unnamed: D30.C, IC4.7 (OUT2)
unnamed: D31.C, IC4.8 (OUT3)
unnamed: D32.C, IC4.9 (OUT4)
unnamed: D34.C, IC4.11 (OUT6)
unnamed: D35.C, IC4.12 (OUT7)
unnamed: D99.C, IC4.13 (OUT8)
unnamed: D98.C, IC4.14 (OUT9)
unnamed: D97.C, IC4.15 (OUT10)
unnamed: D96.C, IC4.16 (OUT11)
unnamed: D95.C, IC4.17 (OUT12)
unnamed: D94.C, IC4.18 (OUT13)
unnamed: D93.C, IC4.19 (OUT14)
unnamed: D92.C, IC4.20 (OUT15)
unnamed: D33.C, IC4.10 (OUT5)
unnamed: IC4.23 (IREF), R15.1
unnamed: D20.C, IC3.5 (OUT0)
unnamed: D21.C, IC3.6 (OUT1)
unnamed: D22.C, IC3.7 (OUT2)
unnamed: D23.C, IC3.8 (OUT3)
unnamed: D24.C, IC3.9 (OUT4)
unnamed: D26.C, IC3.11 (OUT6)
unnamed: D27.C, IC3.12 (OUT7)
unnamed: D91.C, IC3.13 (OUT8)
unnamed: D90.C, IC3.14 (OUT9)
unnamed: D89.C, IC3.15 (OUT10)
unnamed: D88.C, IC3.16 (OUT11)
unnamed: D87.C, IC3.17 (OUT12)
unnamed: D86.C, IC3.18 (OUT13)
unnamed: D85.C, IC3.19 (OUT14)
unnamed: D84.C, IC3.20 (OUT15)
unnamed: D25.C, IC3.10 (OUT5)
unnamed: IC3.23 (IREF), R14.1
unnamed: D60.C, IC8.5 (OUT0)
unnamed: D61.C, IC8.6 (OUT1)
unnamed: D62.C, IC8.7 (OUT2)
unnamed: D63.C, IC8.8 (OUT3)
unnamed: D64.C, IC8.9 (OUT4)
unnamed: D66.C, IC8.11 (OUT6)
unnamed: D67.C, IC8.12 (OUT7)
unnamed: D131.C, IC8.13 (OUT8)
unnamed: D130.C, IC8.14 (OUT9)
unnamed: D129.C, IC8.15 (OUT10)
unnamed: D128.C, IC8.16 (OUT11)
unnamed: D127.C, IC8.17 (OUT12)
unnamed: D126.C, IC8.18 (OUT13)
unnamed: D125.C, IC8.19 (OUT14)
unnamed: D124.C, IC8.20 (OUT15)
unnamed: D65.C, IC8.10 (OUT5)
unnamed: IC8.23 (IREF), R19.1
unnamed: D12.C, IC2.5 (OUT0)
unnamed: D13.C, IC2.6 (OUT1)
unnamed: D14.C, IC2.7 (OUT2)
unnamed: D15.C, IC2.8 (OUT3)
unnamed: D16.C, IC2.9 (OUT4)
unnamed: D18.C, IC2.11 (OUT6)
unnamed: D19.C, IC2.12 (OUT7)
unnamed: D83.C, IC2.13 (OUT8)
unnamed: D82.C, IC2.14 (OUT9)
unnamed: D81.C, IC2.15 (OUT10)
unnamed: D80.C, IC2.16 (OUT11)
unnamed: D79.C, IC2.17 (OUT12)
unnamed: D78.C, IC2.18 (OUT13)
unnamed: D77.C, IC2.19 (OUT14)
unnamed: D76.C, IC2.20 (OUT15)
unnamed: D17.C, IC2.10 (OUT5)
unnamed: IC2.23 (IREF), R13.1
unnamed: D4.C, IC1.5 (OUT0)
unnamed: D5.C, IC1.6 (OUT1)
unnamed: D6.C, IC1.7 (OUT2)
unnamed: D7.C, IC1.8 (OUT3)
unnamed: D8.C, IC1.9 (OUT4)
unnamed: D10.C, IC1.11 (OUT6)
unnamed: D11.C, IC1.12 (OUT7)
unnamed: D75.C, IC1.13 (OUT8)
unnamed: D74.C, IC1.14 (OUT9)
unnamed: D73.C, IC1.15 (OUT10)
unnamed: D72.C, IC1.16 (OUT11)
unnamed: D71.C, IC1.17 (OUT12)
unnamed: D70.C, IC1.18 (OUT13)
unnamed: D69.C, IC1.19 (OUT14)
unnamed: D68.C, IC1.20 (OUT15)
unnamed: D9.C, IC1.10 (OUT5)
unnamed: IC1.23 (IREF), R12.1
unnamed: D188.C, IC16.5 (OUT0)
unnamed: D573.C, IC40.6 (OUT1)
unnamed: D189.C, IC16.6 (OUT1)
unnamed: D574.C, IC40.7 (OUT2)
unnamed: D190.C, IC16.7 (OUT2)
unnamed: D191.C, IC16.8 (OUT3)
unnamed: D192.C, IC16.9 (OUT4)
unnamed: D194.C, IC16.11 (OUT6)
unnamed: D195.C, IC16.12 (OUT7)
unnamed: D259.C, IC16.13 (OUT8)
unnamed: D258.C, IC16.14 (OUT9)
unnamed: D257.C, IC16.15 (OUT10)
unnamed: D256.C, IC16.16 (OUT11)
unnamed: D255.C, IC16.17 (OUT12)
unnamed: D254.C, IC16.18 (OUT13)
unnamed: D253.C, IC16.19 (OUT14)
unnamed: D252.C, IC16.20 (OUT15)
unnamed: D193.C, IC16.10 (OUT5)
unnamed: IC16.23 (IREF), R27.1
unnamed: D180.C, IC15.5 (OUT0)
unnamed: D181.C, IC15.6 (OUT1)
unnamed: D182.C, IC15.7 (OUT2)
unnamed: D183.C, IC15.8 (OUT3)
unnamed: D184.C, IC15.9 (OUT4)
unnamed: D186.C, IC15.11 (OUT6)
unnamed: D187.C, IC15.12 (OUT7)
unnamed: D251.C, IC15.13 (OUT8)
unnamed: D250.C, IC15.14 (OUT9)
unnamed: D249.C, IC15.15 (OUT10)
unnamed: D248.C, IC15.16 (OUT11)
unnamed: D247.C, IC15.17 (OUT12)
unnamed: D246.C, IC15.18 (OUT13)
unnamed: D245.C, IC15.19 (OUT14)
unnamed: D244.C, IC15.20 (OUT15)
unnamed: D185.C, IC15.10 (OUT5)
unnamed: IC15.23 (IREF), R26.1
unnamed: D172.C, IC14.5 (OUT0)
unnamed: D173.C, IC14.6 (OUT1)
unnamed: D174.C, IC14.7 (OUT2)
unnamed: D175.C, IC14.8 (OUT3)
unnamed: D176.C, IC14.9 (OUT4)
unnamed: D178.C, IC14.11 (OUT6)
unnamed: D179.C, IC14.12 (OUT7)
unnamed: D243.C, IC14.13 (OUT8)
unnamed: D242.C, IC14.14 (OUT9)
unnamed: D241.C, IC14.15 (OUT10)
unnamed: D240.C, IC14.16 (OUT11)
unnamed: D239.C, IC14.17 (OUT12)
unnamed: D238.C, IC14.18 (OUT13)
unnamed: D237.C, IC14.19 (OUT14)
unnamed: D236.C, IC14.20 (OUT15)
unnamed: D177.C, IC14.10 (OUT5)
unnamed: IC14.23 (IREF), R25.1
unnamed: D164.C, IC13.5 (OUT0)
unnamed: D165.C, IC13.6 (OUT1)
unnamed: D166.C, IC13.7 (OUT2)
unnamed: D167.C, IC13.8 (OUT3)
unnamed: D168.C, IC13.9 (OUT4)
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

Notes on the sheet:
COLUNA 1
COLUNA 2
COLUNA 3
COLUNA 4
RIREF (khoms) = (1.208V / ILED (mA)) x 43.8 * 43.8 / 10k x 1.208V = 5.29104 mA / LED * 5.25104mA x 512 = 2 709 mA
DC-DC 8-36V / 5V 5A
Dissipação por IC = 0.115W Dissipação Total = 7.36W
SCHOTTKY !

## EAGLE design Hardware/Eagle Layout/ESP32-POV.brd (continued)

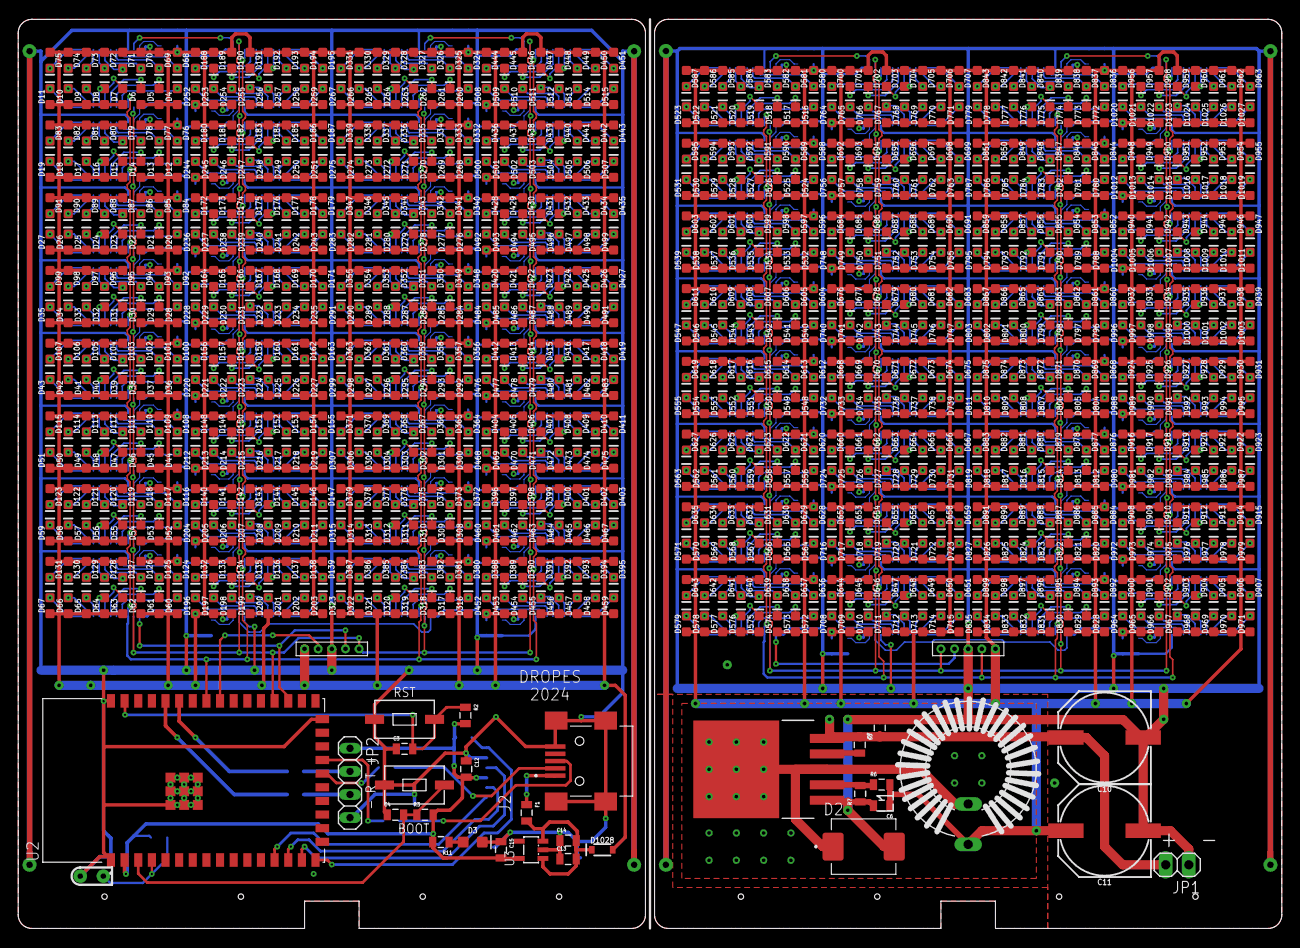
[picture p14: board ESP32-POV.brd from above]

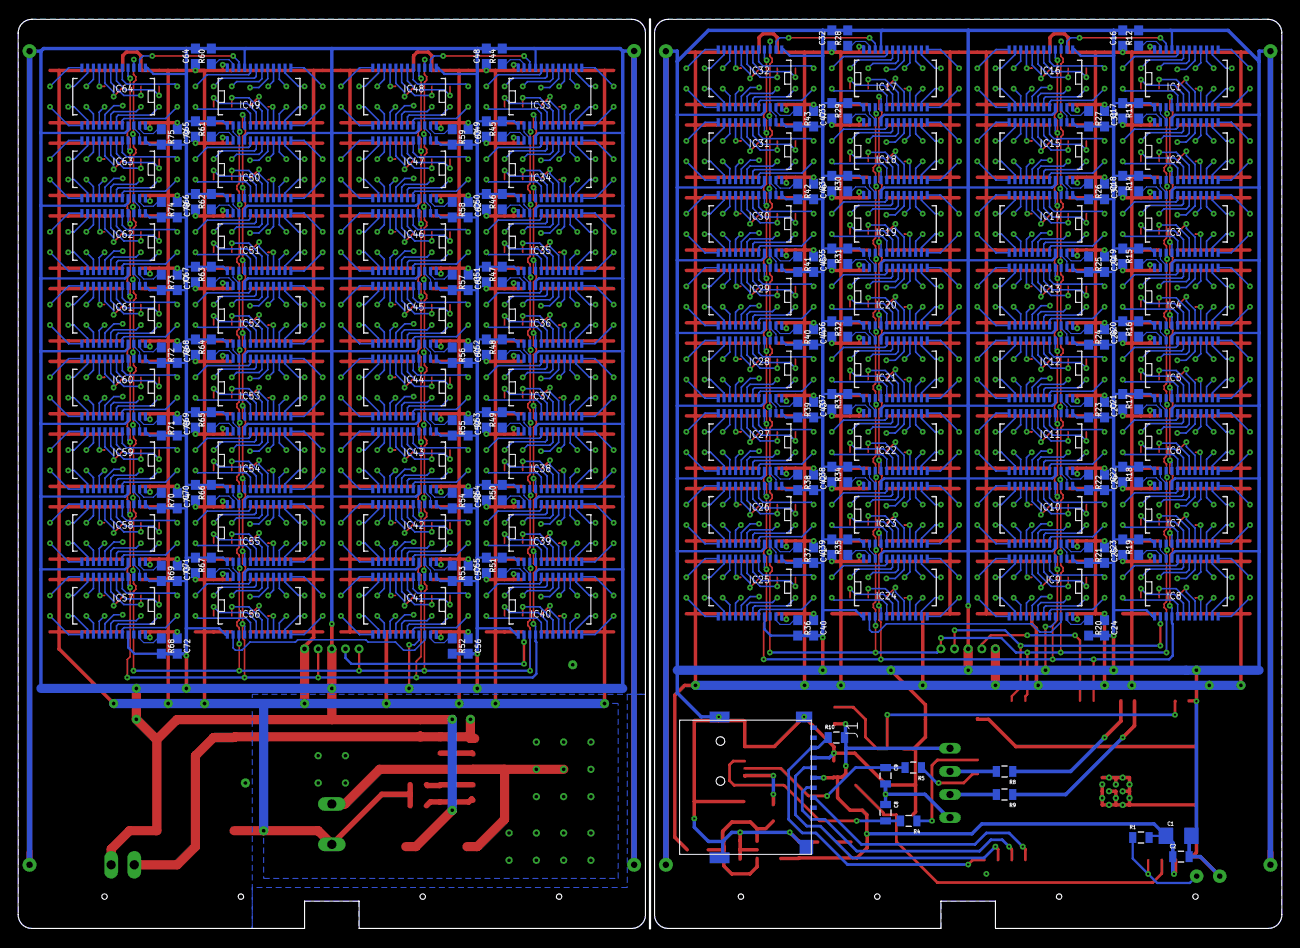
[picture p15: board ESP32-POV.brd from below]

Board: 2 copper layers, 139.0 x 100.0 mm, 1259 parts (203 on the bottom side), 1180 nets.

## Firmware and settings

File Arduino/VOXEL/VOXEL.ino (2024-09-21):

///////////////////////////////
// V O X E L by #dropes 2024 //
///////////////////////////////

//wifi
#include <WiFi.h>
#include <ESPmDNS.h>
#include <WiFiUdp.h>
#include <ArduinoOTA.h>
//spi
#include <SPI.h>
//cube
#include <Arduino.h>
//#include <math.h>

//FX
#include "Shared.h"
#include "00_CubeStatic.h" 
#include "01_SolarSystem.h"
#include "02_Sphere.h"     
#include "03_Cube3axis.h"  
#include "04_Torus.h"      
#include "05_SineX2.h"     
#include "06_Orbital.h"    
#include "07_Rain.h"       
#include "08_Star.h"       
#include "09_Bouncing.h"   
#include "10_Arrows.h"     
#include "11_Tornado.h"  
#include "12_PlanetaryGearbox.h"  
#include "13_DNA.h"
#include "14_Spirals.h"
#include "15_SnakeCube.h"
#include "16_Snakes.h"
#include "17_Bubbles.h"
#include "18_Tetrahedrons.h"
#include "19_Firework.h"  

#define FXlast 19

#define MATRIX_WIDTH 32
#define MATRIX_HEIGHT 32
#define ANGLES 100

#define HSPI_MISO 37
#define HSPI_MOSI 35
#define HSPI_SCLK 36
#define HSPI_CS 34
#define LE1 41
#define LE2 40
#define IR_PIN 1


//15000000;  //TLC59283: Data transfer rate: 35MHz "Ghosts :(" MAX=17MHz
static const int spiClk = 15000000;  
SPIClass* hspi = NULL;

// Timer0 Configuration Pointer (Handle)
hw_timer_t* timer = NULL;

//Enter your sensitive data to connect to Wi-Fi
const char* ssid = "..."; // your network SSID (name) */
const char* password = "..."; // your network password (use for WPA, or use as key for WEP) */

uint8_t currentAngle, newAngle;
int hys = 3000;

uint8_t blank[MATRIX_HEIGHT * 2];
uint32_t buf_matrix[MATRIX_HEIGHT];


unsigned long lastIRTrigger = 0;
unsigned long rotationTime = 0;  // Time for one rotation in milliseconds
unsigned long currentState;
unsigned long timePerSegment;

float rotate = 0.0;
int deg = 0;
int deg_old = 0;
float deg_inc = 0.0;
uint8_t FX = 0;
int FX_count = 0;
uint8_t oldFX = 0;
int frame = 0; //for animations

uint8_t seq_yx[16][4] = {
  { 48, 47, 16, 15 },
  { 49, 46, 17, 14 },
  { 50, 45, 18, 13 },
  { 51, 44, 19, 12 },
  { 52, 43, 20, 11 },
  { 53, 42, 21, 10 },
  { 54, 41, 22, 9 },
  { 55, 40, 23, 8 },
  { 56, 39, 24, 7 },
  { 57, 38, 25, 6 },
  { 58, 37, 26, 5 },
  { 59, 36, 27, 4 },
  { 60, 35, 28, 3 },
  { 61, 34, 29, 2 },
  { 62, 33, 30, 1 },
  { 63, 32, 31, 0 }
};


//------------------------------------------------------------------------------
//------------------------------------------------------------------------------

//----------------------------------Rectangular to polar conversion
void rec2pol(uint32_t *arr, int angle) {

 // 100x faster when assigning just the angle to be displayed
 // for (int angle = 0; angle < angles; angle++) { 

    // negative angle for the 2nd board
    int Iangle;
    if (angle < 49) //*50
      Iangle = angle + 47; //*47 esq/dto
    else
      Iangle = angle + 46; //*46 frt/back
    if (Iangle > 99) 
      Iangle -= 100; 
    //float Itheta = (2 * PI * Iangle) / ANGLES;

    int IangleAdd = Iangle + 3;  //*3 
    if (IangleAdd > 99)
      IangleAdd -= 100;

    for (int r = 0; r < 16; r++) {
      int x1 = round(center + r * cosT[angle]);
      int y1 = round(center + r * sinT[angle]);
      int x2 = round(center + r * cosT[Iangle]);
      int y2 = round(center + r * sinT[Iangle]);

      for (int z = 0; z < MATRIX_HEIGHT; z++) {
        //1st board
        if (GET_BIT(arr, x1, y1, z)) {
          Polar[z][angle] |= (1UL << (r + 16));
        }
        if (GET_BIT(arr, x2, y2, z)) {
          Polar[z][angle] |= (1UL << (15 - r));
        }
        z++;
        //2nd board
        if (GET_BIT(arr, x1, y1, z)) {
          Polar[z][IangleAdd] |= (1UL << (r + 16));
        }
        if (GET_BIT(arr, x2, y2, z)) {
          Polar[z][IangleAdd] |= (1UL << (15 - r));
        }
      }
    }
 // }
}

//----------------------------------Convert the matrix for both boards
void matrix2brd() {  // This procedure must be quick
  uint8_t value_1;
  uint8_t value_2;
  uint8_t xy_loc;

  uint32_t value_up;
  uint32_t value_down;

  // captures the image from the buffer matrix
  for (uint8_t y = 0; y < 32; y += 2) {
    value_up = buf_matrix[y];
    value_down = buf_matrix[y + 1];
    for (int x = 3; x > -1; x--) {
      value_1 = value_up & 0XFF;
      value_2 = value_down & 0XFF;

      // places the byte in the final position and orientation to be displayed.
      xy_loc = seq_yx[y >> 1][x];

      if (y % 4 == 0) {  //y= 0 4 8 12
        buf_brd_1[xy_loc] = reverse(value_1);
        buf_brd_2[xy_loc] = reverse(value_2);
      } else {
        buf_brd_1[xy_loc] = value_1;
        buf_brd_2[xy_loc] = value_2;
      }
      value_up >>= 8;
      value_down >>= 8;
    }
  }
}

//----------------------------------Clear LEDs
void clearLEDs() {
  digitalWrite(LE1, LOW);
  digitalWrite(LE2, LOW);
  hspi->writeBytes(blank, 64);
  digitalWrite(LE1, HIGH);
  digitalWrite(LE2, HIGH);
  digitalWrite(LE1, LOW);
  digitalWrite(LE2, LOW);
}

//----------------------------------Rectangular 32x32 - Polar 32x32/ang - Matrix 32x32- Board 2x32x16
void rec2brd(uint8_t angleSet) {
  rec2pol(voxelGrid, angleSet);
  for (uint8_t z = 0; z < MATRIX_HEIGHT; z++) {
    buf_matrix[z] = Polar[z][angleSet];
  }
  matrix2brd();
}

//----------------------------------Interrupt routine for NEW IMAGE
void ARDUINO_ISR_ATTR Tm() {

  switch (FX) {
    case 0:  //CubeStatic rotates on Z
      if (rotate < 100.0) rotate += 0.01;
      else rotate = 0;
      newAngle = currentAngle + round(rotate);
      if (newAngle > 99) newAngle -= 100;
      rec2brd(newAngle);
      break;

    case 1:  //Solar System
      rec2brd(currentAngle);
      break;

    case 2:  //Sphere
      rec2brd(currentAngle);
      if (currentAngle == 99) clearLEDs();
      break;

    case 3:  //Cube3axi
      rec2brd(currentAngle);
      break;

    case 4:  //Torus
      rec2brd(currentAngle);
      if (currentAngle == 99) clearLEDs();
      break;

    case 5:  //SineX2
      if (deg_inc < 359) deg_inc += 0.03;
      else deg_inc = 0;
      deg = (int)deg_inc;
      if (deg != deg_old) showSine(deg);
      if (currentAngle % 4 == 0) {
        memcpy(buf_brd_1, buff1, sizeof(buff1));
        memcpy(buf_brd_2, buff2, sizeof(buff2));
      } else {
        memset(buf_brd_1, 0, sizeof(buf_brd_1));
        memset(buf_brd_2, 0, sizeof(buf_brd_2));
      }
      deg_old = deg;
      break;

    case 6:  //Orbital
      rec2brd(currentAngle);
      if (currentAngle == 99) clearLEDs();
      break;

    case 7:  //Rain
      rec2brd(currentAngle);
      break;

    case 8:  //Star
      //Rotate the Star
      if (rotate < 100.0) rotate += 0.01;
      else rotate = 0;
      newAngle = currentAngle + round(rotate);
      if (newAngle > 99) newAngle -= 100;
      rec2pol(voxelGrid, newAngle);
      for (uint8_t z = 0; z < MATRIX_HEIGHT; z++) {
        buf_matrix[z] = Polar[z][newAngle];
        if (random(50) == 1) {
          buf_matrix[z] |= (1 << (micros() & 0b11111));  //sparks :)
        }
      }
      matrix2brd();
      break;

    case 9 ... 19:  //Bouncing Ball, Arrows, Tornado, Planetary Gearbox, DNA, Spirals, SnakeCube, Snakes, Bubbles, Tetrahedrons, Firework
        rec2brd(currentAngle);
        break;
  }

  digitalWrite(LE1, LOW);
  hspi->writeBytes(buf_brd_1, 64);
  digitalWrite(LE1, HIGH);
  digitalWrite(LE1, LOW);

  digitalWrite(LE2, LOW);
  hspi->writeBytes(buf_brd_2, 64);
  digitalWrite(LE2, HIGH);
  digitalWrite(LE2, LOW);

  if (currentAngle == 99) {
    timerStop(timer);
  } else currentAngle++;
}


//----------------------------------IR interrupt routine for Segment Time
void ISR_IR() {
  unsigned long currentTime = micros();
  // Check if HYS ms have passed since the last trigger
  if (currentTime - lastIRTrigger >= hys) {
    timePerSegment = round((currentTime - lastIRTrigger) / 100.5);
    lastIRTrigger = currentTime;

    currentAngle = 0;
    timerStop(timer);  //it should also stop at angle 99 (time counter reset)
    timerAlarm(timer, timePerSegment, true, 0);
    timerStart(timer);

    switch (FX) {
      case 0:  // CubeStatic rotates on Z
        drawCube();
        oldFX = FX;
        break;

      case 1:  //Solar System
        memset(voxelGrid, 0, sizeof(voxelGrid));
        memset(Polar, 0, sizeof(Polar));
        drawSolarSystem3D();
        oldFX = FX;
        break;

      case 2:  // Sphere
        if (oldFX != FX) {
          initSphere();
        }
        memset(voxelGrid, 0, sizeof(voxelGrid));
        memset(Polar, 0, sizeof(Polar));
        updateSphere();
        oldFX = FX;
        break;

      case 3:  //Cube3axi
        if (oldFX != FX) {
          angleXf = 0.0;
          angleYf = 0.0;
          angleZf = 0.0;
        }
        updateRotatedCube();
        oldFX = FX;
        break;

      case 4:  //Torus rotates on 3 axes
        if (oldFX != FX) {
          angleXi = 0;
          angleYi = 0;
          angleZi = 0;
        }
        memset(voxelGrid, 0, sizeof(voxelGrid));
        memset(Polar, 0, sizeof(Polar));
        clearLEDs();
        updateTorus();
        oldFX = FX;
        break;

      case 5:  //SineX2
        oldFX = FX;
        break;

      case 6:  //Orbital
        if (oldFX != FX) {
          clearLEDs();  //Removes traces
        }
        // Clear previous drawings
        memset(voxelGrid, 0, sizeof(voxelGrid));
        memset(Polar, 0, sizeof(Polar));
        updateOrbital();
        oldFX = FX;
        break;

      case 7:  //Rain
        if (oldFX != FX) {
          memset(voxelGrid, 0, sizeof(voxelGrid));
        }
        memset(Polar, 0, sizeof(Polar));
        updateRain();  // Update the rain pattern
        oldFX = FX;
        break;

      case 8:  //Star
        if (oldFX != FX) {
          // Clear previous drawings
          memset(voxelGrid, 0, sizeof(voxelGrid));
          memset(Polar, 0, sizeof(Polar));
          drawStarOfDavid(voxelGrid);
        }
        oldFX = FX;
        break;

      case 9:  //Bouncing Ball
        if (oldFX != FX) {
          initBalls();
          frame = 0;
        }
        if (frame == 0) {
          memset(voxelGrid, 0, sizeof(voxelGrid));
          memset(Polar, 0, sizeof(Polar));
          updateBalls();
          frame = 1;
        } else frame = 0;
        oldFX = FX;
        break;

      case 10:  //Arrows
        if (oldFX != FX) {
          memset(voxelGrid, 0, sizeof(voxelGrid));
          // Initialize all lines as inactive at start
          for (int i = 0; i < maxLines; i++) {
            lines[i].active = false;
          }
        }
        memset(Polar, 0, sizeof(Polar));
        if (millis() - lastUpdate > updateInterval) {
          lastUpdate = millis();
          updateArrows();
        }
        oldFX = FX;
        break;

      case 11:  //Tornado
        if (oldFX != FX) {
          initializeParticles();
          initializeDebris();  // Initialize debris
        }
        memset(voxelGrid, 0, sizeof(voxelGrid));
        memset(Polar, 0, sizeof(Polar));
        updateTornado();
        oldFX = FX;
        break;

      case 12:  //Planetary Gearbox
        if (oldFX != FX) frame = 0;
        memset(Polar, 0, sizeof(Polar));
        frame = (frame + 1) % NUM_FRAMES;
        memcpy(voxelGrid, animationFrames[frame], sizeof(voxelGrid));
        oldFX = FX;
        break;

      case 13:  //DNA
        memset(voxelGrid, 0, sizeof(voxelGrid));
        memset(Polar, 0, sizeof(Polar));
        updateDNA();
        oldFX = FX;
        break;

      case 14:  //Spirals
        if (oldFX != FX) deg = 0;
        memset(voxelGrid, 0, sizeof(voxelGrid));
        memset(Polar, 0, sizeof(Polar));    
        drawSpirals(deg);
        deg = (deg + 3) % 360;  // Rotate over time
        oldFX = FX;
        break;

      case 15:  //SnakeCube
        if (oldFX != FX) {
          initSnakeCube();
        }
        memset(voxelGrid, 0, sizeof(voxelGrid));
        memset(Polar, 0, sizeof(Polar));
        updateCubeEdges();
        oldFX = FX;
        break;

      case 16:  //Snakes
        if (oldFX != FX) {  // Initialize all snakes
          for (int i = 0; i < MAX_SNAKES; i++) {
            initializeSnake(snakes[i]);
          }
        }
        memset(voxelGrid, 0, sizeof(voxelGrid));
        memset(Polar, 0, sizeof(Polar));
        updateSnakes();
        oldFX = FX;
        break;
      
      case 17: //Bubbles
        if (FX != oldFX) {
          initializeBubbles();
        }  
        memset(voxelGrid, 0, sizeof(voxelGrid));
        memset(Polar, 0, sizeof(Polar));
        updateBubbles();
        oldFX = FX;
        break;

      case 18: //Tetrahedrons
        memset(voxelGrid, 0, sizeof(voxelGrid));
        memset(Polar, 0, sizeof(Polar));
        drawTetra();
        oldFX = FX;
        break;
        
      case 19:  //Firework (This must be the LAST effect)
        if (oldFX != FX) {
          launchInterval = random(300, 1000);  // Set initial random launch interval original=500 / 2000
        }
        memset(voxelGrid, 0, sizeof(voxelGrid));
        memset(Polar, 0, sizeof(Polar));
        unsigned long currTime = millis();  //"currentTime" variable is already used (micros);
        // Check if it's time to launch the next firework
        if (currTime - lastLaunchTime >= launchInterval) {
          for (int i = 0; i < MAX_FIREWORKS; i++) {
            if (fireworks[i].state == INACTIVE) {
              launchFirework(i);                  // Launch a new firework
              lastLaunchTime = currTime;          // Reset the launch time
              launchInterval = random(200, 600);  // Set the next random interval
              i = MAX_FIREWORKS;                  // Launch one firework at a time
            }
          }
        }
        updateFireworks();  // Update all fireworks
        oldFX = FX;
        break;
    }
  }

  //----------------

  if (FX_count == 500) { // Time per animation
    if (FX < FXlast) FX++;  //FX % FXtotal
    else FX = 0;
    FX_count = 0;
  } else FX_count++;
}

//----------------------------------SETUP
void setup() {

  hspi = new SPIClass(HSPI);
  hspi->begin(HSPI_SCLK, HSPI_MISO, HSPI_MOSI, HSPI_CS);  //SCLK, MISO, MOSI, SS

  pinMode(IR_PIN, INPUT);
  pinMode(LE1, OUTPUT);
  pinMode(LE2, OUTPUT);

  //Clear all LEDs
  hspi->beginTransaction(SPISettings(spiClk, MSBFIRST, SPI_MODE0));
  clearLEDs();
  hspi->endTransaction();

  randomSeed(analogRead(0));  // Initialize random number generator
  memset(persistenceGrid, 0, sizeof(persistenceGrid));

  allocateAnimationFrames();
  precalculatePlanetaryGearboxAnimation();

//FX=16;
//oldFX=15;

  //Serial.begin(115200); just for debugging
  WiFi.mode(WIFI_STA);
  WiFi.begin(ssid, password);

  ArduinoOTA
    .onStart([]() {
      String type;
      if (ArduinoOTA.getCommand() == U_FLASH)
        type = "sketch";
      else  // U_SPIFFS
        type = "filesystem";
      // NOTE: if updating SPIFFS this would be the place to unmount SPIFFS using SPIFFS.end()
    })
    .onEnd([]() {
    })
    .onProgress([](unsigned int progress, unsigned int total) {
    })
    .onError([](ota_error_t error) {
    });
  ArduinoOTA.begin();
  hspi->beginTransaction(SPISettings(spiClk, MSBFIRST, SPI_MODE0));

  // Configure Timer0 Interrupt . the remaining configuration is inside the int IR
  timer = timerBegin(1000000);       //timer 1Mhz resolution
  timerAttachInterrupt(timer, &Tm);  //attach callback

  delay(500);
  attachInterrupt(digitalPinToInterrupt(IR_PIN), ISR_IR, FALLING);  // IR int = Falling, in Rising it shakes a little
  
}

//----------------------------------LOOP
void loop() {
  ArduinoOTA.handle();
}

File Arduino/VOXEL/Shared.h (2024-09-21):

//----------------------------------SHARED

#define ANGLES 100
#define SIZE 32
#define SIZE_2 16

// Center point (between LED 15 and LED 16)
const float center = 15.5;
const float center2 = center * center;

uint32_t voxelGrid[1024] = {0}; // 32x32x32 grid, each bit is a voxel
uint32_t (*animationFrames)[1024];  // Pointer to store the animation frames in PSRAM

// Define the matrix as an array of uint32_t, with each bit representing an LED
uint32_t Polar[SIZE][ANGLES];

uint8_t buf_brd_1[SIZE * 2];
uint8_t buf_brd_2[SIZE * 2];
uint8_t buff1[SIZE * 2];
uint8_t buff2[SIZE * 2];

//----------------------------------RAIN

uint8_t persistenceGrid[32][32] = {0}; // Counters for last level persistence 
uint32_t layerBuffers[32][32]; // Buffer for entire layers

//---------------------------------BOUNCING BALLS

#define FIELD_SIZE 30 //32 must be pair
#define BALL_RADIUS 5
#define BALL_DIAMETER (2 * BALL_RADIUS)
#define FIELD_RADIUS (FIELD_SIZE / 2)
#define NUM_BALLS 3

struct Ball {
    int8_t x, y, z;     // Ball position
    int8_t dx, dy, dz;  // Ball direction
};

Ball balls[NUM_BALLS];  // Array of balls

//----------------------------------ARROWS

// Structure to manage line states
struct Line {
  int fixed1, fixed2;  // Fixed coordinates (depends on the axis of movement)
  int moving;          // Current position (moving coordinate)
  int direction;       // Direction (-1 or 1)
  int length;          // Length of the line
  bool active;         // Is the line currently active
  int axis;            // 0 = move along X, 1 = move along Y, 2 = move along Z
};

const int maxLines = 20;    // Maximum number of simultaneous lines
Line lines[maxLines];       // Array to hold the state of each line
unsigned long lastUpdate = 0;
const int updateInterval = 8;  // Speed of movement (in milliseconds)

//----------------------------------TORNADO

#define TABLE_SIZE 360

#define NUM_PARTICLES 100  // Number of particles in the tornado
#define TORNADO_SIZE 32
#define TORNADO_SIZE_2 16
#define TORNADO_RADIUS 10  // Maximum radius of the tornado
#define TORNADO_HEIGHT TORNADO_SIZE  // Height of the tornado

struct Particle {
    float x, y, z;       // Position
    int angleIndex;      // Angle index for lookup table
    float height;        // Height of the particle
};

Particle particles[NUM_PARTICLES];  // Array of particles

//---

#define NUM_DEBRIS 30  // Number of debris particles
#define MAX_DEBRIS_RADIUS (TORNADO_SIZE / 2 - 2)  // Maximum radius for debris, leaving a margin at the boundary
#define MIN_SPEED 100   // Minimum speed for particles far from the tornado
#define MAX_SPEED 300   // Maximum speed for particles close to the tornado


struct Debris {
    float x, y, z;       // Position
    float initialRadius; // Initial radius from the tornado center
    int angleIndex;      // Angle index for lookup table
    float height;        // Fixed height
    float speed;
};

Debris debris[NUM_DEBRIS];  // Array of debris particles

//----------------------------------VOXEL / SPHERE / TORUS

float angleXf = 0.0;
float angleYf = 0.0;
float angleZf = 0.0;

int angleXi = 0;
int angleYi = 0;
int angleZi = 0;

//----------------------------------SOLAR SYSTEM

// Tilt angles for 3D orbits (in degrees)
float tiltEarth = 23.5;  // Earth's orbital tilt
float tiltMoon = 5.1;    // Moon's orbital tilt

float thetaEarth = 0;
float thetaMoon = 0;
float speedEarth = 1;  // Degrees per cycle
float speedMoon = 5;   // Faster orbit around Earth


#define MAX_FLAMES 20  // Maximum number of sparks at any time

struct Flame {
    int x, y, z;
    int life;  // Number of frames the spark will last
    int dx, dy, dz;  // Direction of movement
};

Flame flames[MAX_FLAMES];

//----------------------------------PLANETARY GEARBOXES

#define NUM_FRAMES 360

//----------------------------------DNA

static float rotationAngle = 0;
uint8_t traceGrid[SIZE][SIZE][SIZE];  // Stores the lifetime of trace bits

//----------------------------------SNAKE CUBE

// Define constants for the maximum number of cubes
#define MAX_CUBES 5

// Struct to hold cube properties
struct Vertex {
    int x, y, z;
};

struct Cube {
    int currentPhase;
    float edgeProgress;
    bool erasing;
    Vertex vertices[8];   // 8 vertices for each cube
};

//----------------------------------SNAKES

#define MAX_SNAKES 10
#define SNAKE_LENGTH 15  // Length of each snake
#define DIRECTIONS 6      // Number of possible directions (up, down, left, right, forward, backward)

// Struct to define each snake
struct Snake {
    Vertex body[SNAKE_LENGTH];  // Body segments of the snake
    int headDirection;          // Current direction of movement
};

//----------------------------------BUBBLES

struct Bubble {
  int x, y, z;      // Center position of the bubble
  float zPosition;  // Store the Z position as a float for smooth movement
  int radius;       // Radius of the bubble
  float speed;      // Speed at which the bubble rises
  bool active;      // Whether the bubble is currently visible
};

const int MAX_BUBBLES = 50;  // Maximum number of bubbles at a time
Bubble bubbles[MAX_BUBBLES];

//----------------------------------FIREWORKS

#define GRID_LAYER_SIZE (SIZE * SIZE)
#define TOTAL_VOXELS (SIZE * SIZE * SIZE)
#define MAX_SPARKS 50           // Maximum number of sparks per explosion
#define SPARK_LIFETIME 20       // How many frames each spark lasts
#define MAX_FIREWORKS 5         // Maximum number of simultaneous fireworks
#define LAUNCH_INTERVAL 10      // Time between each firework launch step (in ms)
#define RADIUS (SIZE / 2)
#define CENTER (SIZE / 2)
#define START_Z 31


// Spark structure to hold the properties of each spark
struct Spark {
    float x, y, z;               // Current position of the spark
    float dx, dy, dz;            // Direction of movement
    int lifetime;                // Frames remaining before the spark disappears
};

// Firework states
enum FireworkState { INACTIVE, LAUNCHING, EXPLODING };

struct Firework {
    Spark sparks[MAX_SPARKS];    // Array to hold all sparks for this firework
    int numSparks;               // Current number of active sparks
    FireworkState state;         // State of the firework (launching, exploding)
    int startX, startY, startZ;  // Launch position
    int currentZ;                // Current Z position during launch
    unsigned long lastUpdate;    // Last update time for non-blocking delay
};

Firework fireworks[MAX_FIREWORKS];  // Array to hold multiple fireworks

unsigned long lastLaunchTime = 0;  // Track the last time a firework was launched
unsigned long launchInterval;      // Random interval between launches

//----------------------------------
//----------------------------------

#define GET_BIT(arr, x, y, z) ((arr[(z * 32 * 32 + y * 32 + x) / 32] >> (x % 32)) & 1UL)

#define SAFE_INDEX(x, y, z) (((z) * 32 * 32 + (y) * 32 + (x)) / 32)
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

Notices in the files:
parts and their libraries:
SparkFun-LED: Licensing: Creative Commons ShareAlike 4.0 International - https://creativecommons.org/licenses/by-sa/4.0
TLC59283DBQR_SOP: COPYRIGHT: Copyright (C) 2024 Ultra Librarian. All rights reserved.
